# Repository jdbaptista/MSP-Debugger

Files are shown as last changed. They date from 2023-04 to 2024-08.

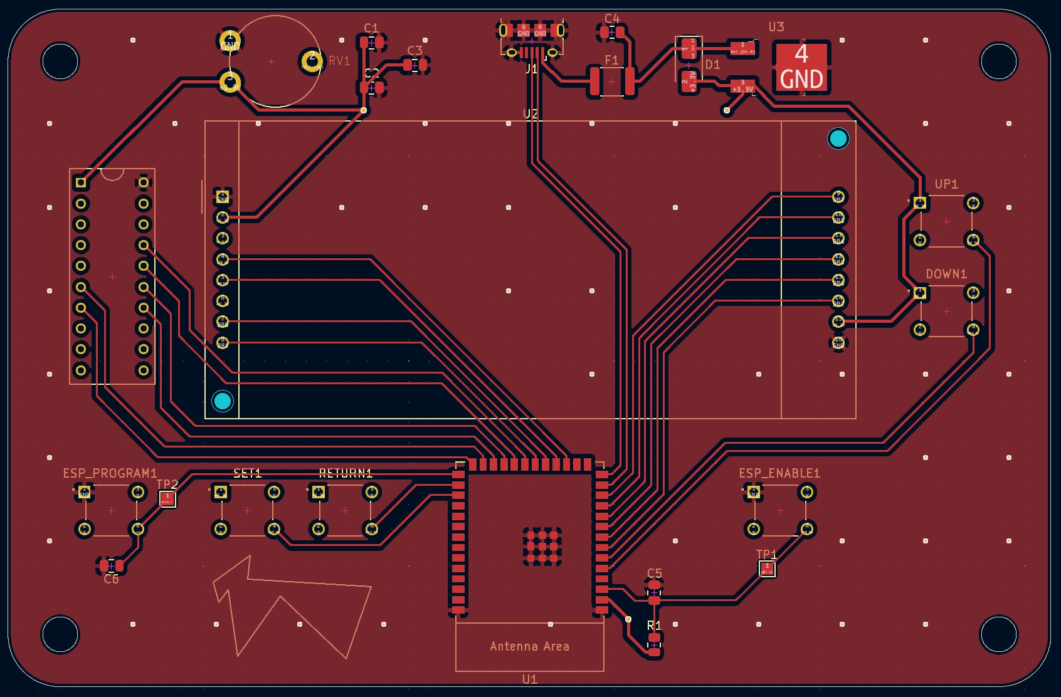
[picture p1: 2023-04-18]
Hardware/frontpcb.jpg

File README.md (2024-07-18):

## Introduction
This project is a combination of bare-metal firmware and hardware that displays the assembly instructions stored in the flash memory of an MSP430G2553, specifically the 20 pin DIP package. Please navigate to each section as necessary: [Example Operation](#example-operation), [Firmware](#firmware).

The device is shown below and supports the following button interactions:
* **UP**: Move back one instruction. Note that moving back one instruction is equivalent to moving lower in memory because the program counter increments positively each target CPU cycle.
  
* **DOWN**: Move forward one instruction. Note that moving forward one instruction is equivalent to moving higher in memory because the program counter increments positively each target CPU cycle.
  
* **FOLLOW JMP**: When the cursor is on a jump instruction, this button moves the cursor to the location specified by the jump. There is also support for following call instructions when the destination operand is an immediate or PC relative offset.
  
* **BIN <-> ASM**: Switch the display view between machine code (binary), displayed in hexadecimal, and RISC assembly instructions. This button highlights that assembly instructions on the target correspond to variable length machine code due to operand types.
  
* **RESET**: Move the cursor back to `0xC000`, which is the start of code memory. This is implemented by simply resetting the MCU.
  
* **USB RESET**: Reset the USB to UART bridge. USB data lines are currently in a broken state, so this button does nothing.

<br>
<p align="center">

</p>

## Example Operation
The following example code from Texas Instruments is used in this example of the device's operation. The code blinks P1.0 repeatedly. Note that all assembly instructions displayed by the device are confirmed to be correct by Code Composer Studio's professional disassembler.
```C
#include <msp430.h>				

void main(void)
{
	WDTCTL = WDTPW | WDTHOLD;		// stop watchdog timer
	P1DIR |= 0x01;					// configure P1.0 as output

	volatile unsigned int i;		// volatile to prevent optimization

	while(1)
	{
		P1OUT ^= 0x01;				// toggle P1.0
		for(i=10000; i>0; i--);     // delay
	}
}
```
The target is loaded with the assembled machine code for this program and placed in the MSP-Debugger. Unfortunately, the display and USB to UART bridge are currently broken, so an MSP-FET (from any MSP430 development board) is connected to the JTAG header of the debugger. The MSP-FET's backchannel UART to USB bridge is used to convey instructions to the user, operating at **9600 baud with an 8-bit frame, no parity bit, and importantly 2 stop bits** (for data integrity). The UART encoding is ISO-8859-1, which is the default in CCS. Immediately after **RESET** the following instruction are extracted from the target and displayed.
```
0xC000: SUB.B #2 SP <
0xC002: MOV.B #0x5A80 &0x0120
0xC008: BIS.B #1 &0x0022
0xC00C: XOR.B #1 &0x0021
```
Using the **DOWN** button moves the cursor from `0xC000` to `0xC002`.
```
0xC002: MOV.B #0x5A80 &0x0120 <
0xC008: BIS.B #1 &0x0022
0xC00C: XOR.B #1 &0x0021
0xC010: MOV.B #0x2710 0x0000(SP)
```
An extremely well trained eye will recognize `&0x0120` as the location of the `WDTCTL` register, which can be confirmed by the peripheral file map on page 18 of the [MSP430G2x53 Datasheet](https://www.ti.com/lit/ds/symlink/msp430g2553.pdf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). Someone without access to the C source code can reference page 363 of the [MSP430G2xx User Guide](https://www.ti.com/lit/ug/slau144k/slau144k.pdf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) to determine that the value `#0x5A80` being moved into `WDTCTL` register writes the correct watchdog password `0x5A00` (`WDTPW`) and suspends the watchdog's operation with `0x0080` (`WDTHOLD`). The watchdog timer will reset the microcontroller if not 'pet' in time by setting `WDTCNTCL`, so this instruction allows the microcontroller to operate without fear of the watchdog.

Using the **BIN <-> ASM** button switches the display from assembly to machine code.
```
0xC002: 0x40B2 0x5A80 0x0120 <
0xC008: 0xD3D2 0x0022 
0xC00C: 0xE3D2 0x0021 
0xC010: 0x40B1 0x2710 0x0000 
```
In this view it can be seen that the instruction to suspend the watchdog takes 3 words, ie. 48 bits, to encode. This is because the `MOV` instruction is a double operand instruction type and the opcode `0x40B2` specifies immediate mode for the first operand, which stores the immediate in the second word, and absolute mode for the second operand, which stores its address in the third word. These modes are internally specified by indirect autoincrement mode with the PC register and indexed mode with the SR register, respectively.

The while loop on line 1 should correspond to a jump instruction somewhere in memory, which we navigate forward to discover.
```
0xC01A: JEQ 0xC00C <
0xC01C: SUB.B #1 0x0000(SP)
0xC020: CMP.B #0 0x0000(SP)
0xC024: JEQ 0xC00C
```
The first jump instruction found is at `0xC01A`, jumping to `0xC00C`. This isn't useful in itself because we don't know what was being compared, which was an instruction that was skipped over.

Using the **UP** button moves the cursor backward by one instruction.
```
0xC016: CMP.B #0 0x0000(SP) <
0xC01A: JEQ 0xC00C
0xC01C: SUB.B #1 0x0000(SP)
0xC020: CMP.B #0 0x0000(SP)
```
This instruction is comparing 0 to some variable located at the stack pointer. This should be `i` from line 12 of the source code because it is the only variable on the stack. Therefore, the jump must correspond to finishing the delay.

Moving the cursor down to the `JEQ 0xC00C` isntruction and using the **FOLLOW JMP** instruction brings the cursor to `0xC00C`.
```
0xC00C: XOR.B #1 &0x0021 <
0xC010: MOV.B #0x2710 0x0000(SP)
0xC016: CMP.B #0 0x0000(SP)
0xC01A: JEQ 0xC00C
```
Finally, it is seen that this `XOR` instruction corresponds to toggling P1.0, as it is the first thing to occur within the while loop!

## Firmware
An MSP430G2553, aside from being the target type, is also used as the main microcontroller for the device. Firmware was developed using register level C programming in Code Composer Studio. Development followed information derived from the [MSP430G2xx User Guide](https://www.ti.com/lit/ug/slau144k/slau144k.pdf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), the [MSP430G2x53 Datasheet](https://www.ti.com/lit/ds/symlink/msp430g2553.pdf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), and the [MSP430 JTAG Programming Guide](https://www.ti.com/lit/ug/slau320aj/slau320aj.pdf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). Three libraries were developed to handle separate facets of the project requirements:

* **UART Driver**: This library handles control of the USCI peripheral to communicate via the UART module. This driver handles configuration of USCI and UART registers, buffering of user printing output, and transmission with a builtin interrupt handler. The driver offers a user-friendly API (ex. `wait_print(char *input)` and `uart_print_hex(uint16_t input)`) optimized for spaced calls. The `wait_print` function is most likely to be used, and currently implements polling until the previous message is finished being sent.
  
* **JTAG Driver**: This library handles interfacing with the target through its JTAG debugging interface. Internally, the interface is implemented as an FSM that is controlled by five input and output lines: TDI, TDO, TMS, TCK, and TEST. This driver works by bit banging the correct FSM sequences on GPIO pins. The API offers a variety of functions (specified by the [JTAG Programming Guide](https://www.ti.com/lit/ug/slau320aj/slau320aj.pdf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)), but the most important for this project is `readMem(uint16_t address)`. This function returns the value stored in the target at a particular memory address.
  
* **Disassembler**: This library handles conversion of machine code to RISC assembly instruction. Information about the representation of each instruction as machine code can be found in the [MSP430G2xx User Guide](https://www.ti.com/lit/ug/slau144k/slau144k.pdf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), specifically the CPU section. The MSP430G2553 contains a 16-bit CPU supporting variable length instructions ranging from a minimum of 1 word to a maximum of 3 words. This presented a significant design challenge as moving one assembly instruction backward is ambiguously a shift of 1, 2, or 3 words in memory with little to hint at which is correct. This ambiguity stems from the various addressing modes (ex. indexed mode) and instruction types (ex. single operand). The disassembler has no remedy to this issue; rather, it is currently solved by the main program which simply begins from the beginning of flash memory and iterates forward until finding the correct instruction. It is planned to speed up this process with a significantly sized cache of nearby instruction locations.

The main program handles user button input with interrupts on the corresponding GPIO pins and a simple button debounce system using the timer peripheral. The program enters LPM3 while waiting for user input, with the timer running on ACLK sourced from the 12kHz VLO waking the program up if a button debounce has finished.

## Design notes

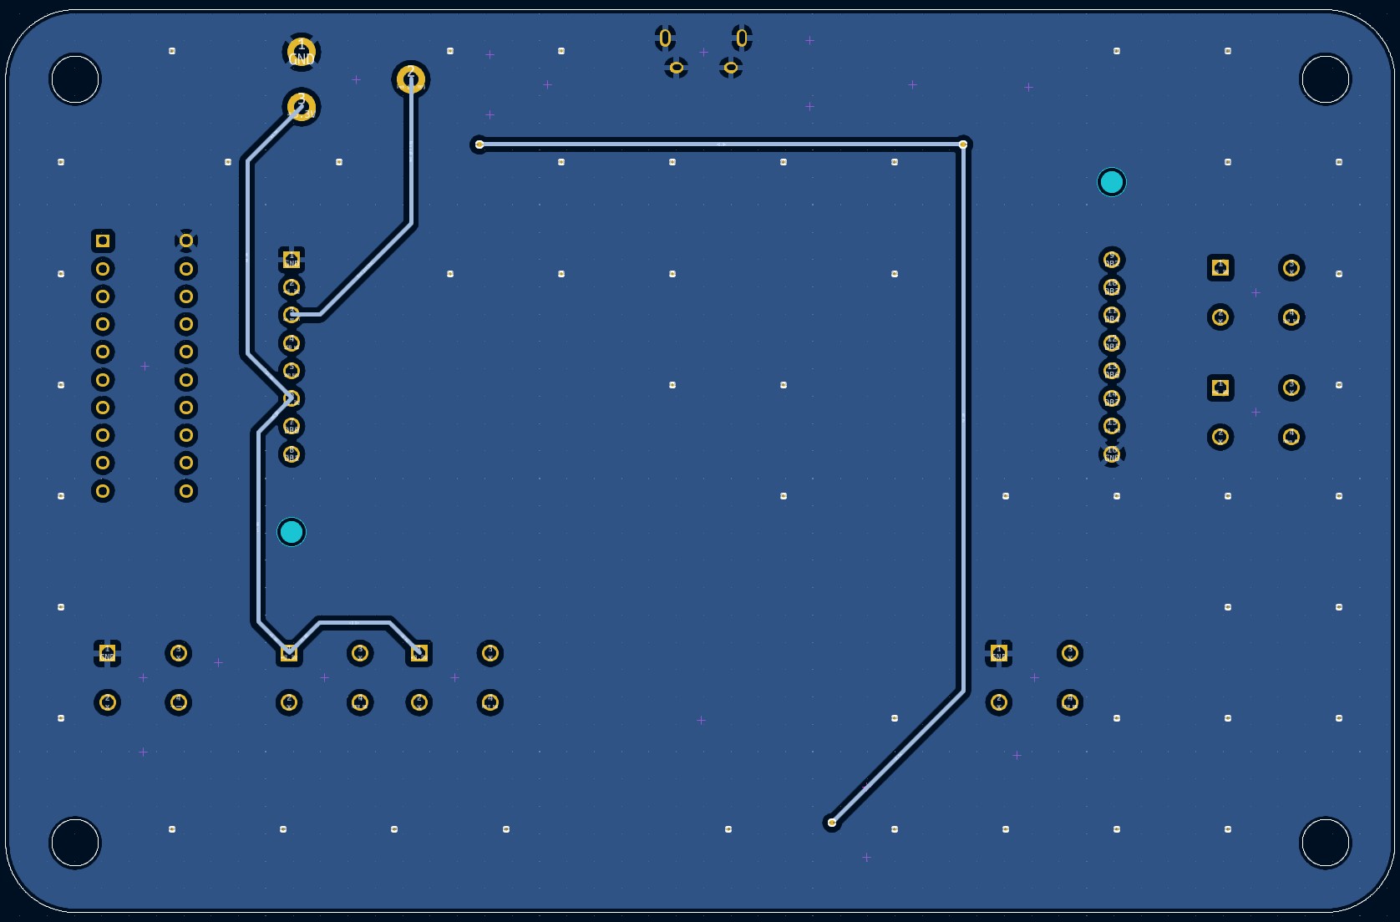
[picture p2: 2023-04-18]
Hardware/backpcb.jpg

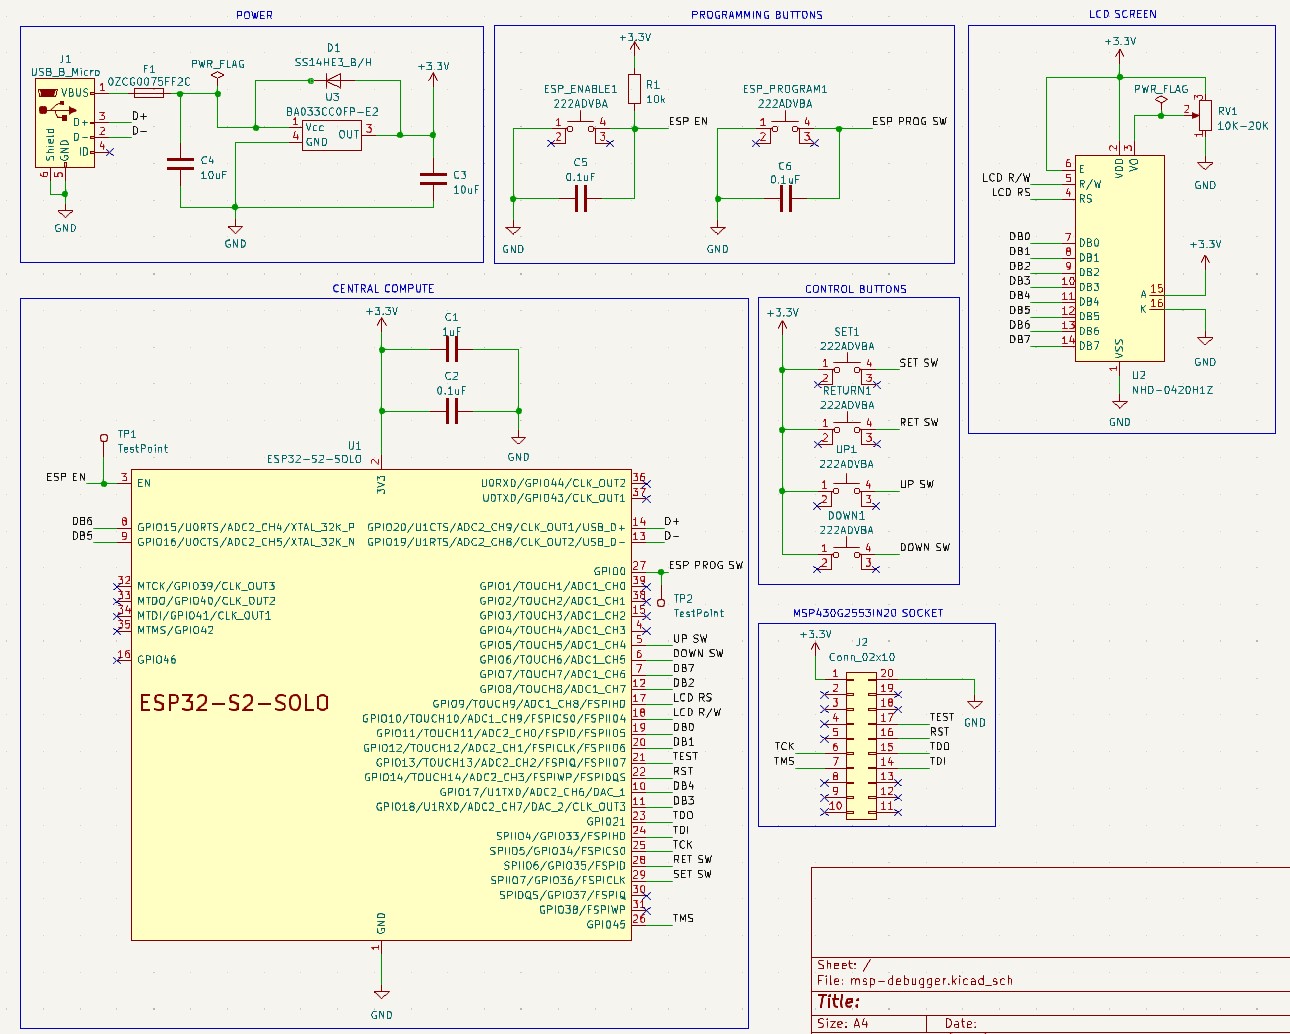
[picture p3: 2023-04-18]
Hardware/schematic.jpg

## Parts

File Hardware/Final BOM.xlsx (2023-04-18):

Custom Reference YOUR NAME (must have) + refdes (optional)! | TOTAL Qty (for 2 boards, or less if budget constrained) | Manufacturer Part # | Digi-key Part#/SKU | Mouser Part#/SKU | Amazon link LAST RESORT | Price/unit ($) | Reference Designator | Description (include component value if applicable)
Jaden Baptista & Anthony Rubio | 1 | NHD-0420H1Z-FSW-GBW-33V3 | NHD-0420H1Z-FSW-GBW-33V3-ND |  |  | $21.38 | U2 | LCD MOD 80DIG 20X4 TRANSFLCT WHT
Jaden Baptista & Anthony Rubio | 1 | PTN10-E20HB20 | 2223-PTN10-E20HB20-ND |  |  | $0.65 | RV1 | TRIMMER POTENTIOMETER, 10MM, HOR
Jaden Baptista & Anthony Rubio | 6 | 222ADVBA | CT3084-ND |  |  | $0.23 | SW(1-6) | SWITCH TACTILE SPST-NO 0.05A 12V
Jaden Baptista & Anthony Rubio | 1 | RC0805JR-0710KL | 311-10KARCT-ND |  |  | $0.10 | R1 | RES 10K OHM 5% 1/8W 0805
Jaden Baptista & Anthony Rubio | 3 | CL21B104KBCNNNC | 1276-1003-1-ND |  |  | $0.10 | C2, C5, C6 | CAP CER 0.1UF 50V X7R 0805
Jaden Baptista & Anthony Rubio | 1 | MSP430G2553IN20 | 296-28429-5-ND |  |  | $3.16 | FLOATING | MSP430 CPU16 MSP430G2xx Microcontroller IC 16-Bit 16MHz 16KB (16K x 8) FLASH 20-PDIP
Jaden Baptista & Anthony Rubio | 1 | 110-83-320-41-001101 | 110-83-320-41-001101-ND |  |  | $2.02 | J2 | CONN IC DIP SOCKET 20POS GOLD
Jaden Baptista & Anthony Rubio | 1 | ESP32-S2-SOLO-2-N4 | 1965-ESP32-S2-SOLO-2-N4-ND |  |  | $2.60 | U1 | WiFi 802.11b/g/n Transceiver Module 2.4GHz PCB Trace Surface Mount
Jaden Baptista & Anthony Rubio | 1 | CL21B105KAFNNNE | 1276-1066-1-ND |  |  | $0.10 | C1 | 1 µF ±10% 25V Ceramic Capacitor X7R 0805 (2012 Metric)
Jaden Baptista & Anthony Rubio | 1 | BA033CC0FP-E2 | BA033CC0FP-E2CT-ND |  |  | $1.41 | U3 | IC REG LINEAR 3.3V 1A TO252-3
Jaden Baptista & Anthony Rubio | 1 | SS14HE3_B/H | 112-SS14HE3_B/HCT-ND |  |  | $0.10 | D1 | Diode 40 V 1A Surface Mount DO-214AC (SMA)
Jaden Baptista & Anthony Rubio | 1 | 10118194-0011LF | 10118194-0011LF-ND |  |  | $0.28 | J1 | USB - micro B USB 2.0 Receptacle Connector 5 Position Surface Mount, Right Angle; Through Hole
Jaden Baptista & Anthony Rubio | 1 | 0ZCG0075FF2C | 507-1763-1-ND |  |  | $0.16 | F1 | PTC RESET FUSE 16V 750MA 1812
Jaden Baptista & Anthony Rubio | 2 | CL21A106KOQNNNE | 1276-1096-1-ND |  |  | $0.10 | C3, C4 | 10 µF ±10% 16V Ceramic Capacitor X5R 0805 (2012 Metric)

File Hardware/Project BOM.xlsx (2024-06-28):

Partner 1 Name: Jaden Baptista | Partner 1 Email: baptistajaden@berkeley.edu | Partner 2 Name: Anthony Rubio | Partner 2 Email: anthonyjrubio@berkeley.edu
 |  |  |  |  |  |  |  |  |  | Total Price for Project
 |  |  |  |  |  |  |  |  |  | $59.54
Qty (for 1 board) | Manufacturer Part # | Digi-key Part#/SKU | Price/unit ($) | Purchase URL | Reference Designator | Description (include component value if applicable) | Datasheet Link | Multiple | Total Qty | Total Price/part ($)
1 | NHD-0440AZ-FL-YBW | NHD-0440AZ-FL-YBW-ND | $28.59 | https://www.digikey.com/en/products/detail/newhaven-display-intl/NHD-0440AZ-FL-YBW/1701247 | U2 | LCD MOD 160 DIG 40X4 TRANS YLW/GRN | https://newhavendisplay.com/content/specs/NHD-0440AZ-FL-YBW.pdf | 1 | 1 | $28.59
10 | RC0805JR-0710KL | 311-10KARCT-ND | $0.10 | https://www.digikey.com/en/products/detail/yageo/RC0805JR-0710KL/728241 | R1 | RES 10K OHM 5% 1/8W 0805 | https://www.yageo.com/upload/media/product/productsearch/datasheet/rchip/PYu-RC_Group_51_RoHS_L_12.pdf | 1 | 10 | $1.00
1 | 3362P-1-103LF | 3362P-103LF-ND | $1.03 | https://www.digikey.com/en/products/detail/bourns-inc/3362P-1-103LF/1088412 | VR1 | TRIMMER 10K OHM 0.5W PC PIN TOP | https://www.bourns.com/docs/Product-Datasheets/3362.pdf | 1 | 1 | $1.03
6 | 222ADVBA | CT3084-ND | $0.23 | https://www.digikey.com/en/products/detail/cts-electrocomponents/222ADVBA/5227977 | SW(1-5) | SWITCH TACTILE SPST-NO 0.05A 12V | https://www.ctscorp.com/wp-content/uploads/222A.pdf | 1 | 6 | $1.38
3 | CL21B104KBCNNNC | 1276-1003-1-ND | $0.10 | https://www.digikey.com/en/products/detail/samsung-electro-mechanics/CL21B104KBCNNNC/3886661 | C2, C5, C6 | CAP CER 0.1UF 50V X7R 0805 | https://media.digikey.com/pdf/Data%20Sheets/Samsung%20PDFs/CL21B104KBCNNN_Spec.pdf | 1 | 3 | $0.30
2 | MSP430G2553IN20 | 296-28429-5-ND | $2.90 | https://www.digikey.com/en/products/detail/texas-instruments/MSP430G2553IN20/2638885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 | U1, J1 | IC MCU 16BIT 16KB FLASH 20DIP | https://www.ti.com/general/docs/suppproductinfo.tsp?distId=10 | 1 | 2 | $5.80
1 | 110-83-320-41-001101 | 110-83-320-41-001101-ND | $2.02 | https://www.digikey.com/en/products/detail/preci-dip/110-83-320-41-001101/4093408 | J2 | CONN IC DIP SOCKET 20POS GOLD | https://www.mouser.com/datasheet/2/571/Preci_Dip_01252017_cat_129-1214522.pdf | 1 | 1 | $2.02
1 | CL21B105KAFNNNE | 1276-1066-1-ND | $0.10 | https://www.digikey.com/en/products/detail/samsung-electro-mechanics/CL21B105KAFNNNE/3886724 | C1 | 1 µF ±10% 25V Ceramic Capacitor X7R 0805 (2012 Metric) | https://media.digikey.com/pdf/Data%20Sheets/Samsung%20PDFs/CL21B105KAFNNNE_Spec.pdf | 1 | 1 | $0.10
1 | BA033CC0FP-E2 | BA033CC0FP-E2CT-ND | $1.41 | https://www.digikey.com/en/products/detail/rohm-semiconductor/BA033CC0FP-E2/722186 | U3 | IC REG LINEAR 3.3V 1A TO252-3 | https://www.rohm.com/datasheet?p=BA033CC0FP&dist=Digi-key&media=referral&campaign=Digi-key | 1 | 1 | $1.41
1 | SS14HE3_B/H | 112-SS14HE3_B/HCT-ND | $0.10 | https://www.digikey.com/en/products/detail/vishay-general-semiconductor-diodes-division/SS14HE3-B-H/6621876 | D1 | Diode 40 V 1A Surface Mount DO-214AC (SMA) | https://www.vishay.com/docs/88746/ss12.pdf | 1 | 1 | $0.10
1 | 10118194-0011LF | 10118194-0011LF-ND | $0.28 | https://www.digikey.com/en/products/detail/amphenol-icc-fci/10118194-0011lf/6817759 | J1 | USB - micro B USB 2.0 Receptacle Connector 5 Position Surface Mount, Right Angle; Through Hole | https://cdn.amphenol-cs.com/media/wysiwyg/files/drawing/10118194.pdf | 1 | 1 | $0.28
1 | 0ZCG0075FF2C | 507-1763-1-ND | $0.16 | https://www.digikey.com/en/products/detail/bel-fuse-inc/0ZCG0075FF2C/4156101 | F1 | PTC RESET FUSE 16V 750MA 1812 | https://www.belfuse.com/resources/datasheets/circuitprotection/ds-cp-0zcg-series.pdf | 1 | 1 | $0.16
2 | CL21A106KOQNNNE | 1276-1096-1-ND | $0.10 | https://www.digikey.com/en/products/detail/samsung-electro-mechanics/CL21A106KOQNNNE/3886754 | C3, C4 | 10 µF ±10% 16V Ceramic Capacitor X5R 0805 (2012 Metric) | https://media.digikey.com/pdf/Data%20Sheets/Samsung%20PDFs/CL21A106KOQNNNE_Spec.pdf | 1 | 2 | $0.20
1 | FT230XS-R | 768-1135-1-ND | $2.26 | https://www.digikey.com/en/products/detail/ftdi-future-technology-devices-international-ltd/FT230XS-R/3029141 | U4 | IC USB SERIAL BASIC UART 16SSOP | https://ftdichip.com/wp-content/uploads/2021/10/DS_FT230X.pdf | 1 | 1 | $2.26
4 | AO4882 | 785-1317-1-ND | $0.52 | https://www.digikey.com/en/products/detail/alpha-omega-semiconductor-inc/AO4882/3060989 |  | Mosfet Array 40V 8A 2W Surface Mount 8-SOIC | https://www.digikey.com/htmldatasheets/production/1034359/0/0/1/ao4882.pdf | 1 | 4 | $2.08
2 | TSW-102-07-G-T | TSW-102-07-G-T-ND | $0.73 | https://www.digikey.com/en/products/detail/samtec-inc/TSW-102-07-G-T/7862063 | J4, J5 | CONN HEADER VERT 6POS 2.54MM | https://mm.digikey.com/Volume0/opasdata/d220001/medias/docus/6129/tsw-xxx-xx-xxx-x-xx-xxx-mkt.pdf | 1 | 2 | $1.46
3 | QPC02SXGN-RC | S9337-ND | $0.10 | https://www.digikey.com/en/products/detail/sullins-connector-solutions/QPC02SXGN-RC/2618262 |  | CONN JUMPER SHORTING .100" GOLD | https://s3.amazonaws.com/catalogspreads-pdf/PAGE128-129%20.100%20JUMPER.pdf | 1 | 3 | 0.3
2 | TD-109-T-A | SAM1114-09-ND | $3.60 | https://www.digikey.com/en/products/detail/samtec-inc/TD-109-T-A/1105549 |  | CONN HEADER VERT 18POS 2.54MM | https://suddendocs.samtec.com/catalog_english/td.pdf | 1 | 2 | 7.2
2 | TS-110-T-A | SAM1112-10-ND | $1.94 | https://www.digikey.com/en/products/detail/samtec-inc/TS-110-T-A/1105484 |  | CONN HEADER VERT 10POS 2.54MM | https://suddendocs.samtec.com/catalog_english/td.pdf | 1 | 2 | 3.88
 |  |  |  |  |  |  |  |  | 0 | 0
 |  |  |  |  |  |  |  |  | 0 | 0
 |  |  |  |  |  |  |  |  | 0 | 0
 |  |  |  |  |  |  |  |  | 0 | 0
 |  |  |  |  |  |  |  |  | 0 | 0
 |  |  |  |  |  |  |  |  | 0 | 0
 |  |  |  |  |  |  |  |  | 0 | 0
 |  |  |  |  |  |  |  |  | 0 | 0
 |  |  |  |  |  |  |  |  | 0 | 0
 |  |  |  |  |  |  |  |  | 0 | 0
 |  |  |  |  |  |  |  |  | 0 | 0
 |  |  |  |  |  |  |  |  | 0 | 0
 |  |  |  |  |  |  |  |  | 0 | 0
 |  |  |  |  |  |  |  |  | 0 | 0
 |  |  |  |  |  |  |  |  | 0 | 0
 |  |  |  |  |  |  |  |  | 0 | 0
 |  |  |  |  |  |  |  |  | 0 | 0
 |  |  |  |  |  |  |  |  | 0 | 0
 |  |  |  |  |  |  |  |  | 0 | 0
 |  |  |  |  |  |  |  |  | 0 | 0
 |  |  |  |  |  |  |  |  | 0 | 0
 |  |  |  |  |  |  |  |  | 0 | 0
 |  |  |  |  |  |  |  |  | 0 | 0
 |  |  |  |  |  |  |  |  | 0 | 0
 |  |  |  |  |  |  |  |  | 0 | 0
 |  |  |  |  |  |  |  |  | 0 | 0
 |  |  |  |  |  |  |  |  | 0 | 0
 |  |  |  |  |  |  |  |  | 0 | 0
 |  |  |  |  |  |  |  |  | 0 | 0
 |  |  |  |  |  |  |  |  | 0 | 0
 |  |  |  |  |  |  |  |  | 0 | 0
 |  |  |  |  |  |  |  |  | 0 | 0
 |  |  |  |  |  |  |  |  | 0 | 0
 |  |  |  |  |  |  |  |  | 0 | 0
 |  |  |  |  |  |  |  |  | 0 | 0
 |  |  |  |  |  |  |  |  | 0 | 0
 |  |  |  |  |  |  |  |  | 0 | 0
 |  |  |  |  |  |  |  |  | 0 | 0
 |  |  |  |  |  |  |  |  | 0 | 0
 |  |  |  |  |  |  |  |  | 0 | 0
 |  |  |  |  |  |  |  |  | 0 | 0
 |  |  |  |  |  |  |  |  | 0 | 0
 |  |  |  |  |  |  |  |  | 0 | 0
 |  |  |  |  |  |  |  |  | 0 | 0
 |  |  |  |  |  |  |  |  | 0 | 0
 |  |  |  |  |  |  |  |  | 0 | 0
 |  |  |  |  |  |  |  |  | 0 | 0
 |  |  |  |  |  |  |  |  | 0 | 0
 |  |  |  |  |  |  |  |  | 0 | 0
 |  |  |  |  |  |  |  |  | 0 | 0
 |  |  |  |  |  |  |  |  | 0 | 0
 |  |  |  |  |  |  |  |  | 0 | 0
 |  |  |  |  |  |  |  |  | 0 | 0
 |  |  |  |  |  |  |  |  | 0 | 0
 |  |  |  |  |  |  |  |  | 0 | 0
 |  |  |  |  |  |  |  |  | 0 | 0
 |  |  |  |  |  |  |  |  | 0 | 0
 |  |  |  |  |  |  |  |  | 0 | 0
 |  |  |  |  |  |  |  |  | 0 | 0
 |  |  |  |  |  |  |  |  | 0 | 0
 |  |  |  |  |  |  |  |  | 0 | 0
 |  |  |  |  |  |  |  |  | 0 | 0
 |  |  |  |  |  |  |  |  | 0 | 0
 |  |  |  |  |  |  |  |  | 0 | 0
 |  |  |  |  |  |  |  |  | 0 | 0
 |  |  |  |  |  |  |  |  | 0 | 0
 |  |  |  |  |  |  |  |  | 0 | 0
 |  |  |  |  |  |  |  |  | 0 | 0
 |  |  |  |  |  |  |  |  | 0 | 0
 |  |  |  |  |  |  |  |  | 0 | 0
 |  |  |  |  |  |  |  |  | 0 | 0
 |  |  |  |  |  |  |  |  | 0 | 0
 |  |  |  |  |  |  |  |  | 0 | 0
 |  |  |  |  |  |  |  |  | 0 | 0
 |  |  |  |  |  |  |  |  | 0 | 0
 |  |  |  |  |  |  |  |  | 0 | 0
 |  |  |  |  |  |  |  |  | 0 | 0
 |  |  |  |  |  |  |  |  | 0 | 0
 |  |  |  |  |  |  |  |  | 0 | 0
 |  |  |  |  |  |  |  |  | 0 | 0
 |  |  |  |  |  |  |  |  | 0 | 0
 |  |  |  |  |  |  |  |  | 0 | 0
 |  |  |  |  |  |  |  |  | 0 | 0
 |  |  |  |  |  |  |  |  | 0 | 0
 |  |  |  |  |  |  |  |  | 0 | 0
 |  |  |  |  |  |  |  |  | 0 | 0
 |  |  |  |  |  |  |  |  | 0 | 0
 |  |  |  |  |  |  |  |  | 0 | 0
 |  |  |  |  |  |  |  |  | 0 | 0
 |  |  |  |  |  |  |  |  | 0 | 0
 |  |  |  |  |  |  |  |  | 0 | 0
 |  |  |  |  |  |  |  |  | 0 | 0
 |  |  |  |  |  |  |  |  | 0 | 0
 |  |  |  |  |  |  |  |  | 0 | 0
 |  |  |  |  |  |  |  |  | 0 | 0
 |  |  |  |  |  |  |  |  | 0 | 0
 |  |  |  |  |  |  |  |  | 0 | 0
 |  |  |  |  |  |  |  |  | 0 | 0
 |  |  |  |  |  |  |  |  | 0 | 0
 |  |  |  |  |  |  |  |  | 0 | 0
 |  |  |  |  |  |  |  |  | 0 | 0
 |  |  |  |  |  |  |  |  | 0 | 0
 |  |  |  |  |  |  |  |  | 0 | 0
 |  |  |  |  |  |  |  |  | 0 | 0
 |  |  |  |  |  |  |  |  | 0 | 0
 |  |  |  |  |  |  |  |  | 0 | 0
 |  |  |  |  |  |  |  |  | 0 | 0
 |  |  |  |  |  |  |  |  | 0 | 0
 |  |  |  |  |  |  |  |  | 0 | 0
 |  |  |  |  |  |  |  |  | 0 | 0
 |  |  |  |  |  |  |  |  | 0 | 0
 |  |  |  |  |  |  |  |  | 0 | 0
 |  |  |  |  |  |  |  |  | 0 | 0
 |  |  |  |  |  |  |  |  | 0 | 0
 |  |  |  |  |  |  |  |  | 0 | 0
 |  |  |  |  |  |  |  |  | 0 | 0
 |  |  |  |  |  |  |  |  | 0 | 0
 |  |  |  |  |  |  |  |  | 0 | 0
 |  |  |  |  |  |  |  |  | 0 | 0
 |  |  |  |  |  |  |  |  | 0 | 0
 |  |  |  |  |  |  |  |  | 0 | 0
 |  |  |  |  |  |  |  |  | 0 | 0
 |  |  |  |  |  |  |  |  | 0 | 0
 |  |  |  |  |  |  |  |  | 0 | 0
 |  |  |  |  |  |  |  |  | 0 | 0
 |  |  |  |  |  |  |  |  | 0 | 0
 |  |  |  |  |  |  |  |  | 0 | 0
 |  |  |  |  |  |  |  |  | 0 | 0
 |  |  |  |  |  |  |  |  | 0 | 0
 |  |  |  |  |  |  |  |  | 0 | 0
 |  |  |  |  |  |  |  |  | 0 | 0
 |  |  |  |  |  |  |  |  | 0 | 0
 |  |  |  |  |  |  |  |  | 0 | 0
 |  |  |  |  |  |  |  |  | 0 | 0
 |  |  |  |  |  |  |  |  | 0 | 0
 |  |  |  |  |  |  |  |  | 0 | 0
 |  |  |  |  |  |  |  |  | 0 | 0
 |  |  |  |  |  |  |  |  | 0 | 0
 |  |  |  |  |  |  |  |  | 0 | 0
 |  |  |  |  |  |  |  |  | 0 | 0
 |  |  |  |  |  |  |  |  | 0 | 0
 |  |  |  |  |  |  |  |  | 0 | 0
 |  |  |  |  |  |  |  |  | 0 | 0
 |  |  |  |  |  |  |  |  | 0 | 0
 |  |  |  |  |  |  |  |  | 0 | 0
 |  |  |  |  |  |  |  |  | 0 | 0
 |  |  |  |  |  |  |  |  | 0 | 0
 |  |  |  |  |  |  |  |  | 0 | 0
 |  |  |  |  |  |  |  |  | 0 | 0
 |  |  |  |  |  |  |  |  | 0 | 0
 |  |  |  |  |  |  |  |  | 0 | 0
 |  |  |  |  |  |  |  |  | 0 | 0
 |  |  |  |  |  |  |  |  | 0 | 0
 |  |  |  |  |  |  |  |  | 0 | 0
 |  |  |  |  |  |  |  |  | 0 | 0
 |  |  |  |  |  |  |  |  | 0 | 0
 |  |  |  |  |  |  |  |  | 0 | 0
 |  |  |  |  |  |  |  |  | 0 | 0
 |  |  |  |  |  |  |  |  | 0 | 0
 |  |  |  |  |  |  |  |  | 0 | 0
 |  |  |  |  |  |  |  |  | 0 | 0
 |  |  |  |  |  |  |  |  | 0 | 0
 |  |  |  |  |  |  |  |  | 0 | 0
 |  |  |  |  |  |  |  |  | 0 | 0
 |  |  |  |  |  |  |  |  | 0 | 0
 |  |  |  |  |  |  |  |  | 0 | 0
 |  |  |  |  |  |  |  |  | 0 | 0
 |  |  |  |  |  |  |  |  | 0 | 0
 |  |  |  |  |  |  |  |  | 0 | 0
 |  |  |  |  |  |  |  |  | 0 | 0
 |  |  |  |  |  |  |  |  | 0 | 0
 |  |  |  |  |  |  |  |  | 0 | 0
 |  |  |  |  |  |  |  |  | 0 | 0
 |  |  |  |  |  |  |  |  | 0 | 0
 |  |  |  |  |  |  |  |  | 0 | 0
 |  |  |  |  |  |  |  |  | 0 | 0
 |  |  |  |  |  |  |  |  | 0 | 0
 |  |  |  |  |  |  |  |  | 0 | 0
 |  |  |  |  |  |  |  |  | 0 | 0
 |  |  |  |  |  |  |  |  | 0 | 0
 |  |  |  |  |  |  |  |  | 0 | 0
 |  |  |  |  |  |  |  |  | 0 | 0
 |  |  |  |  |  |  |  |  | 0 | 0
 |  |  |  |  |  |  |  |  | 0 | 0
 |  |  |  |  |  |  |  |  | 0 | 0
 |  |  |  |  |  |  |  |  | 0 | 0
 |  |  |  |  |  |  |  |  | 0 | 0
 |  |  |  |  |  |  |  |  | 0 | 0
 |  |  |  |  |  |  |  |  | 0 | 0
 |  |  |  |  |  |  |  |  | 0 | 0
 |  |  |  |  |  |  |  |  | 0 | 0
 |  |  |  |  |  |  |  |  | 0 | 0
 |  |  |  |  |  |  |  |  | 0 | 0
 |  |  |  |  |  |  |  |  | 0 | 0
 |  |  |  |  |  |  |  |  | 0 | 0
 |  |  |  |  |  |  |  |  | 0 | 0
 |  |  |  |  |  |  |  |  | 0 | 0
 |  |  |  |  |  |  |  |  | 0 | 0
 |  |  |  |  |  |  |  |  | 0 | 0
 |  |  |  |  |  |  |  |  | 0 | 0
 |  |  |  |  |  |  |  |  | 0 | 0
 |  |  |  |  |  |  |  |  | 0 | 0
 |  |  |  |  |  |  |  |  | 0 | 0
 |  |  |  |  |  |  |  |  | 0 | 0
 |  |  |  |  |  |  |  |  | 0 | 0
 |  |  |  |  |  |  |  |  | 0 | 0
 |  |  |  |  |  |  |  |  | 0 | 0
 |  |  |  |  |  |  |  |  | 0 | 0
 |  |  |  |  |  |  |  |  | 0 | 0
 |  |  |  |  |  |  |  |  | 0 | 0
 |  |  |  |  |  |  |  |  | 0 | 0
 |  |  |  |  |  |  |  |  | 0 | 0
 |  |  |  |  |  |  |  |  | 0 | 0
 |  |  |  |  |  |  |  |  | 0 | 0
 |  |  |  |  |  |  |  |  | 0 | 0
 |  |  |  |  |  |  |  |  | 0 | 0
 |  |  |  |  |  |  |  |  | 0 | 0
 |  |  |  |  |  |  |  |  | 0 | 0
 |  |  |  |  |  |  |  |  | 0 | 0
 |  |  |  |  |  |  |  |  | 0 | 0
 |  |  |  |  |  |  |  |  | 0 | 0
 |  |  |  |  |  |  |  |  | 0 | 0
 |  |  |  |  |  |  |  |  | 0 | 0
 |  |  |  |  |  |  |  |  | 0 | 0
 |  |  |  |  |  |  |  |  | 0 | 0
 |  |  |  |  |  |  |  |  | 0 | 0
 |  |  |  |  |  |  |  |  | 0 | 0
 |  |  |  |  |  |  |  |  | 0 | 0
 |  |  |  |  |  |  |  |  | 0 | 0
 |  |  |  |  |  |  |  |  | 0 | 0
 |  |  |  |  |  |  |  |  | 0 | 0
 |  |  |  |  |  |  |  |  | 0 | 0
 |  |  |  |  |  |  |  |  | 0 | 0
 |  |  |  |  |  |  |  |  | 0 | 0
 |  |  |  |  |  |  |  |  | 0 | 0
 |  |  |  |  |  |  |  |  | 0 | 0
 |  |  |  |  |  |  |  |  | 0 | 0
 |  |  |  |  |  |  |  |  | 0 | 0
 |  |  |  |  |  |  |  |  | 0 | 0
 |  |  |  |  |  |  |  |  | 0 | 0
 |  |  |  |  |  |  |  |  | 0 | 0
 |  |  |  |  |  |  |  |  | 0 | 0
 |  |  |  |  |  |  |  |  | 0 | 0
 |  |  |  |  |  |  |  |  | 0 | 0
 |  |  |  |  |  |  |  |  | 0 | 0
 |  |  |  |  |  |  |  |  | 0 | 0
 |  |  |  |  |  |  |  |  | 0 | 0
 |  |  |  |  |  |  |  |  | 0 | 0
 |  |  |  |  |  |  |  |  | 0 | 0
 |  |  |  |  |  |  |  |  | 0 | 0
 |  |  |  |  |  |  |  |  | 0 | 0
 |  |  |  |  |  |  |  |  | 0 | 0
 |  |  |  |  |  |  |  |  | 0 | 0
 |  |  |  |  |  |  |  |  | 0 | 0
 |  |  |  |  |  |  |  |  | 0 | 0
 |  |  |  |  |  |  |  |  | 0 | 0
 |  |  |  |  |  |  |  |  | 0 | 0
 |  |  |  |  |  |  |  |  | 0 | 0
 |  |  |  |  |  |  |  |  | 0 | 0
 |  |  |  |  |  |  |  |  | 0 | 0
 |  |  |  |  |  |  |  |  | 0 | 0
 |  |  |  |  |  |  |  |  | 0 | 0
 |  |  |  |  |  |  |  |  | 0 | 0
 |  |  |  |  |  |  |  |  | 0 | 0
 |  |  |  |  |  |  |  |  | 0 | 0
 |  |  |  |  |  |  |  |  | 0 | 0
 |  |  |  |  |  |  |  |  | 0 | 0
 |  |  |  |  |  |  |  |  | 0 | 0
 |  |  |  |  |  |  |  |  | 0 | 0
 |  |  |  |  |  |  |  |  | 0 | 0
 |  |  |  |  |  |  |  |  | 0 | 0
 |  |  |  |  |  |  |  |  | 0 | 0
 |  |  |  |  |  |  |  |  | 0 | 0
 |  |  |  |  |  |  |  |  | 0 | 0
 |  |  |  |  |  |  |  |  | 0 | 0
 |  |  |  |  |  |  |  |  | 0 | 0
 |  |  |  |  |  |  |  |  | 0 | 0
 |  |  |  |  |  |  |  |  | 0 | 0
 |  |  |  |  |  |  |  |  | 0 | 0
 |  |  |  |  |  |  |  |  | 0 | 0
 |  |  |  |  |  |  |  |  | 0 | 0
 |  |  |  |  |  |  |  |  | 0 | 0
 |  |  |  |  |  |  |  |  | 0 | 0
 |  |  |  |  |  |  |  |  | 0 | 0
 |  |  |  |  |  |  |  |  | 0 | 0
 |  |  |  |  |  |  |  |  | 0 | 0
 |  |  |  |  |  |  |  |  | 0 | 0
 |  |  |  |  |  |  |  |  | 0 | 0
 |  |  |  |  |  |  |  |  | 0 | 0
 |  |  |  |  |  |  |  |  | 0 | 0
 |  |  |  |  |  |  |  |  | 0 | 0
 |  |  |  |  |  |  |  |  | 0 | 0
 |  |  |  |  |  |  |  |  | 0 | 0
 |  |  |  |  |  |  |  |  | 0 | 0
 |  |  |  |  |  |  |  |  | 0 | 0
 |  |  |  |  |  |  |  |  | 0 | 0
 |  |  |  |  |  |  |  |  | 0 | 0
 |  |  |  |  |  |  |  |  | 0 | 0
 |  |  |  |  |  |  |  |  | 0 | 0
 |  |  |  |  |  |  |  |  | 0 | 0
 |  |  |  |  |  |  |  |  | 0 | 0
 |  |  |  |  |  |  |  |  | 0 | 0
 |  |  |  |  |  |  |  |  | 0 | 0
 |  |  |  |  |  |  |  |  | 0 | 0
 |  |  |  |  |  |  |  |  | 0 | 0
 |  |  |  |  |  |  |  |  | 0 | 0
 |  |  |  |  |  |  |  |  | 0 | 0
 |  |  |  |  |  |  |  |  | 0 | 0
 |  |  |  |  |  |  |  |  | 0 | 0
 |  |  |  |  |  |  |  |  | 0 | 0
 |  |  |  |  |  |  |  |  | 0 | 0
 |  |  |  |  |  |  |  |  | 0 | 0
 |  |  |  |  |  |  |  |  | 0 | 0
 |  |  |  |  |  |  |  |  | 0 | 0
 |  |  |  |  |  |  |  |  | 0 | 0
 |  |  |  |  |  |  |  |  | 0 | 0
 |  |  |  |  |  |  |  |  | 0 | 0
 |  |  |  |  |  |  |  |  | 0 | 0
 |  |  |  |  |  |  |  |  | 0 | 0
 |  |  |  |  |  |  |  |  | 0 | 0
 |  |  |  |  |  |  |  |  | 0 | 0
 |  |  |  |  |  |  |  |  | 0 | 0
 |  |  |  |  |  |  |  |  | 0 | 0
 |  |  |  |  |  |  |  |  | 0 | 0
 |  |  |  |  |  |  |  |  | 0 | 0
 |  |  |  |  |  |  |  |  | 0 | 0
 |  |  |  |  |  |  |  |  | 0 | 0
 |  |  |  |  |  |  |  |  | 0 | 0
 |  |  |  |  |  |  |  |  | 0 | 0
 |  |  |  |  |  |  |  |  | 0 | 0
 |  |  |  |  |  |  |  |  | 0 | 0
 |  |  |  |  |  |  |  |  | 0 | 0
 |  |  |  |  |  |  |  |  | 0 | 0
 |  |  |  |  |  |  |  |  | 0 | 0
 |  |  |  |  |  |  |  |  | 0 | 0
 |  |  |  |  |  |  |  |  | 0 | 0
 |  |  |  |  |  |  |  |  | 0 | 0
 |  |  |  |  |  |  |  |  | 0 | 0
 |  |  |  |  |  |  |  |  | 0 | 0
 |  |  |  |  |  |  |  |  | 0 | 0
 |  |  |  |  |  |  |  |  | 0 | 0
 |  |  |  |  |  |  |  |  | 0 | 0
 |  |  |  |  |  |  |  |  | 0 | 0
 |  |  |  |  |  |  |  |  | 0 | 0
 |  |  |  |  |  |  |  |  | 0 | 0
 |  |  |  |  |  |  |  |  | 0 | 0
 |  |  |  |  |  |  |  |  | 0 | 0
 |  |  |  |  |  |  |  |  | 0 | 0
 |  |  |  |  |  |  |  |  | 0 | 0
 |  |  |  |  |  |  |  |  | 0 | 0
 |  |  |  |  |  |  |  |  | 0 | 0
 |  |  |  |  |  |  |  |  | 0 | 0
 |  |  |  |  |  |  |  |  | 0 | 0
 |  |  |  |  |  |  |  |  | 0 | 0
 |  |  |  |  |  |  |  |  | 0 | 0
 |  |  |  |  |  |  |  |  | 0 | 0
 |  |  |  |  |  |  |  |  | 0 | 0
 |  |  |  |  |  |  |  |  | 0 | 0
 |  |  |  |  |  |  |  |  | 0 | 0
 |  |  |  |  |  |  |  |  | 0 | 0
 |  |  |  |  |  |  |  |  | 0 | 0
 |  |  |  |  |  |  |  |  | 0 | 0
 |  |  |  |  |  |  |  |  | 0 | 0
 |  |  |  |  |  |  |  |  | 0 | 0
 |  |  |  |  |  |  |  |  | 0 | 0
 |  |  |  |  |  |  |  |  | 0 | 0
 |  |  |  |  |  |  |  |  | 0 | 0
 |  |  |  |  |  |  |  |  | 0 | 0
 |  |  |  |  |  |  |  |  | 0 | 0
 |  |  |  |  |  |  |  |  | 0 | 0
 |  |  |  |  |  |  |  |  | 0 | 0
 |  |  |  |  |  |  |  |  | 0 | 0
 |  |  |  |  |  |  |  |  | 0 | 0
 |  |  |  |  |  |  |  |  | 0 | 0
 |  |  |  |  |  |  |  |  | 0 | 0
 |  |  |  |  |  |  |  |  | 0 | 0
 |  |  |  |  |  |  |  |  | 0 | 0
 |  |  |  |  |  |  |  |  | 0 | 0
 |  |  |  |  |  |  |  |  | 0 | 0
 |  |  |  |  |  |  |  |  | 0 | 0
 |  |  |  |  |  |  |  |  | 0 | 0
 |  |  |  |  |  |  |  |  | 0 | 0
 |  |  |  |  |  |  |  |  | 0 | 0
 |  |  |  |  |  |  |  |  | 0 | 0
 |  |  |  |  |  |  |  |  | 0 | 0
 |  |  |  |  |  |  |  |  | 0 | 0
 |  |  |  |  |  |  |  |  | 0 | 0
 |  |  |  |  |  |  |  |  | 0 | 0
 |  |  |  |  |  |  |  |  | 0 | 0
 |  |  |  |  |  |  |  |  | 0 | 0
 |  |  |  |  |  |  |  |  | 0 | 0
 |  |  |  |  |  |  |  |  | 0 | 0
 |  |  |  |  |  |  |  |  | 0 | 0
 |  |  |  |  |  |  |  |  | 0 | 0
 |  |  |  |  |  |  |  |  | 0 | 0
 |  |  |  |  |  |  |  |  | 0 | 0
 |  |  |  |  |  |  |  |  | 0 | 0
 |  |  |  |  |  |  |  |  | 0 | 0
 |  |  |  |  |  |  |  |  | 0 | 0
 |  |  |  |  |  |  |  |  | 0 | 0
 |  |  |  |  |  |  |  |  | 0 | 0
 |  |  |  |  |  |  |  |  | 0 | 0
 |  |  |  |  |  |  |  |  | 0 | 0
 |  |  |  |  |  |  |  |  | 0 | 0
 |  |  |  |  |  |  |  |  | 0 | 0
 |  |  |  |  |  |  |  |  | 0 | 0
 |  |  |  |  |  |  |  |  | 0 | 0
 |  |  |  |  |  |  |  |  | 0 | 0
 |  |  |  |  |  |  |  |  | 0 | 0
 |  |  |  |  |  |  |  |  | 0 | 0
 |  |  |  |  |  |  |  |  | 0 | 0
 |  |  |  |  |  |  |  |  | 0 | 0
 |  |  |  |  |  |  |  |  | 0 | 0
 |  |  |  |  |  |  |  |  | 0 | 0
 |  |  |  |  |  |  |  |  | 0 | 0
 |  |  |  |  |  |  |  |  | 0 | 0
 |  |  |  |  |  |  |  |  | 0 | 0
 |  |  |  |  |  |  |  |  | 0 | 0
 |  |  |  |  |  |  |  |  | 0 | 0
 |  |  |  |  |  |  |  |  | 0 | 0
 |  |  |  |  |  |  |  |  | 0 | 0
 |  |  |  |  |  |  |  |  | 0 | 0
 |  |  |  |  |  |  |  |  | 0 | 0
 |  |  |  |  |  |  |  |  | 0 | 0
 |  |  |  |  |  |  |  |  | 0 | 0
 |  |  |  |  |  |  |  |  | 0 | 0
 |  |  |  |  |  |  |  |  | 0 | 0
 |  |  |  |  |  |  |  |  | 0 | 0
 |  |  |  |  |  |  |  |  | 0 | 0
 |  |  |  |  |  |  |  |  | 0 | 0
 |  |  |  |  |  |  |  |  | 0 | 0
 |  |  |  |  |  |  |  |  | 0 | 0
 |  |  |  |  |  |  |  |  | 0 | 0
 |  |  |  |  |  |  |  |  | 0 | 0
 |  |  |  |  |  |  |  |  | 0 | 0
 |  |  |  |  |  |  |  |  | 0 | 0
 |  |  |  |  |  |  |  |  | 0 | 0
 |  |  |  |  |  |  |  |  | 0 | 0
 |  |  |  |  |  |  |  |  | 0 | 0
 |  |  |  |  |  |  |  |  | 0 | 0
 |  |  |  |  |  |  |  |  | 0 | 0
 |  |  |  |  |  |  |  |  | 0 | 0
 |  |  |  |  |  |  |  |  | 0 | 0
 |  |  |  |  |  |  |  |  | 0 | 0
 |  |  |  |  |  |  |  |  | 0 | 0
 |  |  |  |  |  |  |  |  | 0 | 0
 |  |  |  |  |  |  |  |  | 0 | 0
 |  |  |  |  |  |  |  |  | 0 | 0
 |  |  |  |  |  |  |  |  | 0 | 0
 |  |  |  |  |  |  |  |  | 0 | 0
 |  |  |  |  |  |  |  |  | 0 | 0
 |  |  |  |  |  |  |  |  | 0 | 0
 |  |  |  |  |  |  |  |  | 0 | 0
 |  |  |  |  |  |  |  |  | 0 | 0
 |  |  |  |  |  |  |  |  | 0 | 0
 |  |  |  |  |  |  |  |  | 0 | 0
 |  |  |  |  |  |  |  |  | 0 | 0
 |  |  |  |  |  |  |  |  | 0 | 0
 |  |  |  |  |  |  |  |  | 0 | 0
 |  |  |  |  |  |  |  |  | 0 | 0
 |  |  |  |  |  |  |  |  | 0 | 0
 |  |  |  |  |  |  |  |  | 0 | 0
 |  |  |  |  |  |  |  |  | 0 | 0
 |  |  |  |  |  |  |  |  | 0 | 0
 |  |  |  |  |  |  |  |  | 0 | 0
 |  |  |  |  |  |  |  |  | 0 | 0
 |  |  |  |  |  |  |  |  | 0 | 0
 |  |  |  |  |  |  |  |  | 0 | 0
 |  |  |  |  |  |  |  |  | 0 | 0
 |  |  |  |  |  |  |  |  | 0 | 0
 |  |  |  |  |  |  |  |  | 0 | 0
 |  |  |  |  |  |  |  |  | 0 | 0
 |  |  |  |  |  |  |  |  | 0 | 0
 |  |  |  |  |  |  |  |  | 0 | 0
 |  |  |  |  |  |  |  |  | 0 | 0
 |  |  |  |  |  |  |  |  | 0 | 0
 |  |  |  |  |  |  |  |  | 0 | 0
 |  |  |  |  |  |  |  |  | 0 | 0
 |  |  |  |  |  |  |  |  | 0 | 0
 |  |  |  |  |  |  |  |  | 0 | 0
 |  |  |  |  |  |  |  |  | 0 | 0
 |  |  |  |  |  |  |  |  | 0 | 0
 |  |  |  |  |  |  |  |  | 0 | 0
 |  |  |  |  |  |  |  |  | 0 | 0
 |  |  |  |  |  |  |  |  | 0 | 0
 |  |  |  |  |  |  |  |  | 0 | 0
 |  |  |  |  |  |  |  |  | 0 | 0
 |  |  |  |  |  |  |  |  | 0 | 0
 |  |  |  |  |  |  |  |  | 0 | 0
 |  |  |  |  |  |  |  |  | 0 | 0
 |  |  |  |  |  |  |  |  | 0 | 0
 |  |  |  |  |  |  |  |  | 0 | 0
 |  |  |  |  |  |  |  |  | 0 | 0
 |  |  |  |  |  |  |  |  | 0 | 0
 |  |  |  |  |  |  |  |  | 0 | 0
 |  |  |  |  |  |  |  |  | 0 | 0
 |  |  |  |  |  |  |  |  | 0 | 0
 |  |  |  |  |  |  |  |  | 0 | 0
 |  |  |  |  |  |  |  |  | 0 | 0
 |  |  |  |  |  |  |  |  | 0 | 0
 |  |  |  |  |  |  |  |  | 0 | 0
 |  |  |  |  |  |  |  |  | 0 | 0
 |  |  |  |  |  |  |  |  | 0 | 0
 |  |  |  |  |  |  |  |  | 0 | 0
 |  |  |  |  |  |  |  |  | 0 | 0
 |  |  |  |  |  |  |  |  | 0 | 0
 |  |  |  |  |  |  |  |  | 0 | 0
 |  |  |  |  |  |  |  |  | 0 | 0
 |  |  |  |  |  |  |  |  | 0 | 0
 |  |  |  |  |  |  |  |  | 0 | 0
 |  |  |  |  |  |  |  |  | 0 | 0
 |  |  |  |  |  |  |  |  | 0 | 0
 |  |  |  |  |  |  |  |  | 0 | 0
 |  |  |  |  |  |  |  |  | 0 | 0
 |  |  |  |  |  |  |  |  | 0 | 0
 |  |  |  |  |  |  |  |  | 0 | 0
 |  |  |  |  |  |  |  |  | 0 | 0
 |  |  |  |  |  |  |  |  | 0 | 0
 |  |  |  |  |  |  |  |  | 0 | 0
 |  |  |  |  |  |  |  |  | 0 | 0
 |  |  |  |  |  |  |  |  | 0 | 0
 |  |  |  |  |  |  |  |  | 0 | 0
 |  |  |  |  |  |  |  |  | 0 | 0
 |  |  |  |  |  |  |  |  | 0 | 0
 |  |  |  |  |  |  |  |  | 0 | 0
 |  |  |  |  |  |  |  |  | 0 | 0
 |  |  |  |  |  |  |  |  | 0 | 0
 |  |  |  |  |  |  |  |  | 0 | 0
 |  |  |  |  |  |  |  |  | 0 | 0
 |  |  |  |  |  |  |  |  | 0 | 0
 |  |  |  |  |  |  |  |  | 0 | 0
 |  |  |  |  |  |  |  |  | 0 | 0
 |  |  |  |  |  |  |  |  | 0 | 0
 |  |  |  |  |  |  |  |  | 0 | 0
 |  |  |  |  |  |  |  |  | 0 | 0
 |  |  |  |  |  |  |  |  | 0 | 0
 |  |  |  |  |  |  |  |  | 0 | 0
 |  |  |  |  |  |  |  |  | 0 | 0
 |  |  |  |  |  |  |  |  | 0 | 0
 |  |  |  |  |  |  |  |  | 0 | 0
 |  |  |  |  |  |  |  |  | 0 | 0
 |  |  |  |  |  |  |  |  | 0 | 0
 |  |  |  |  |  |  |  |  | 0 | 0
 |  |  |  |  |  |  |  |  | 0 | 0
 |  |  |  |  |  |  |  |  | 0 | 0
 |  |  |  |  |  |  |  |  | 0 | 0
 |  |  |  |  |  |  |  |  | 0 | 0
 |  |  |  |  |  |  |  |  | 0 | 0
 |  |  |  |  |  |  |  |  | 0 | 0
 |  |  |  |  |  |  |  |  | 0 | 0
 |  |  |  |  |  |  |  |  | 0 | 0
 |  |  |  |  |  |  |  |  | 0 | 0
 |  |  |  |  |  |  |  |  | 0 | 0
 |  |  |  |  |  |  |  |  | 0 | 0
 |  |  |  |  |  |  |  |  | 0 | 0
 |  |  |  |  |  |  |  |  | 0 | 0
 |  |  |  |  |  |  |  |  | 0 | 0
 |  |  |  |  |  |  |  |  | 0 | 0
 |  |  |  |  |  |  |  |  | 0 | 0
 |  |  |  |  |  |  |  |  | 0 | 0
 |  |  |  |  |  |  |  |  | 0 | 0
 |  |  |  |  |  |  |  |  | 0 | 0
 |  |  |  |  |  |  |  |  | 0 | 0
 |  |  |  |  |  |  |  |  | 0 | 0
 |  |  |  |  |  |  |  |  | 0 | 0
 |  |  |  |  |  |  |  |  | 0 | 0
 |  |  |  |  |  |  |  |  | 0 | 0
 |  |  |  |  |  |  |  |  | 0 | 0
 |  |  |  |  |  |  |  |  | 0 | 0
 |  |  |  |  |  |  |  |  | 0 | 0
 |  |  |  |  |  |  |  |  | 0 | 0
 |  |  |  |  |  |  |  |  | 0 | 0
 |  |  |  |  |  |  |  |  | 0 | 0
 |  |  |  |  |  |  |  |  | 0 | 0
 |  |  |  |  |  |  |  |  | 0 | 0
 |  |  |  |  |  |  |  |  | 0 | 0
 |  |  |  |  |  |  |  |  | 0 | 0
 |  |  |  |  |  |  |  |  | 0 | 0
 |  |  |  |  |  |  |  |  | 0 | 0
 |  |  |  |  |  |  |  |  | 0 | 0
 |  |  |  |  |  |  |  |  | 0 | 0
 |  |  |  |  |  |  |  |  | 0 | 0
 |  |  |  |  |  |  |  |  | 0 | 0
 |  |  |  |  |  |  |  |  | 0 | 0
 |  |  |  |  |  |  |  |  | 0 | 0
 |  |  |  |  |  |  |  |  | 0 | 0
 |  |  |  |  |  |  |  |  | 0 | 0
 |  |  |  |  |  |  |  |  | 0 | 0
 |  |  |  |  |  |  |  |  | 0 | 0
 |  |  |  |  |  |  |  |  | 0 | 0
 |  |  |  |  |  |  |  |  | 0 | 0
 |  |  |  |  |  |  |  |  | 0 | 0
 |  |  |  |  |  |  |  |  | 0 | 0
 |  |  |  |  |  |  |  |  | 0 | 0
 |  |  |  |  |  |  |  |  | 0 | 0
 |  |  |  |  |  |  |  |  | 0 | 0
 |  |  |  |  |  |  |  |  | 0 | 0
 |  |  |  |  |  |  |  |  | 0 | 0
 |  |  |  |  |  |  |  |  | 0 | 0
 |  |  |  |  |  |  |  |  | 0 | 0
 |  |  |  |  |  |  |  |  | 0 | 0
 |  |  |  |  |  |  |  |  | 0 | 0
 |  |  |  |  |  |  |  |  | 0 | 0
 |  |  |  |  |  |  |  |  | 0 | 0
 |  |  |  |  |  |  |  |  | 0 | 0
 |  |  |  |  |  |  |  |  | 0 | 0
 |  |  |  |  |  |  |  |  | 0 | 0
 |  |  |  |  |  |  |  |  | 0 | 0
 |  |  |  |  |  |  |  |  | 0 | 0
 |  |  |  |  |  |  |  |  | 0 | 0
 |  |  |  |  |  |  |  |  | 0 | 0
 |  |  |  |  |  |  |  |  | 0 | 0
 |  |  |  |  |  |  |  |  | 0 | 0
 |  |  |  |  |  |  |  |  | 0 | 0
 |  |  |  |  |  |  |  |  | 0 | 0
 |  |  |  |  |  |  |  |  | 0 | 0
 |  |  |  |  |  |  |  |  | 0 | 0
 |  |  |  |  |  |  |  |  | 0 | 0
 |  |  |  |  |  |  |  |  | 0 | 0
 |  |  |  |  |  |  |  |  | 0 | 0
 |  |  |  |  |  |  |  |  | 0 | 0
 |  |  |  |  |  |  |  |  | 0 | 0
 |  |  |  |  |  |  |  |  | 0 | 0
 |  |  |  |  |  |  |  |  | 0 | 0
 |  |  |  |  |  |  |  |  | 0 | 0
 |  |  |  |  |  |  |  |  | 0 | 0
 |  |  |  |  |  |  |  |  | 0 | 0
 |  |  |  |  |  |  |  |  | 0 | 0
 |  |  |  |  |  |  |  |  | 0 | 0
 |  |  |  |  |  |  |  |  | 0 | 0
 |  |  |  |  |  |  |  |  | 0 | 0
 |  |  |  |  |  |  |  |  | 0 | 0
 |  |  |  |  |  |  |  |  | 0 | 0
 |  |  |  |  |  |  |  |  | 0 | 0
 |  |  |  |  |  |  |  |  | 0 | 0
 |  |  |  |  |  |  |  |  | 0 | 0
 |  |  |  |  |  |  |  |  | 0 | 0
 |  |  |  |  |  |  |  |  | 0 | 0
 |  |  |  |  |  |  |  |  | 0 | 0
 |  |  |  |  |  |  |  |  | 0 | 0
 |  |  |  |  |  |  |  |  | 0 | 0
 |  |  |  |  |  |  |  |  | 0 | 0
 |  |  |  |  |  |  |  |  | 0 | 0
 |  |  |  |  |  |  |  |  | 0 | 0
 |  |  |  |  |  |  |  |  | 0 | 0
 |  |  |  |  |  |  |  |  | 0 | 0
 |  |  |  |  |  |  |  |  | 0 | 0
 |  |  |  |  |  |  |  |  | 0 | 0
 |  |  |  |  |  |  |  |  | 0 | 0
 |  |  |  |  |  |  |  |  | 0 | 0
 |  |  |  |  |  |  |  |  | 0 | 0
 |  |  |  |  |  |  |  |  | 0 | 0
 |  |  |  |  |  |  |  |  | 0 | 0
 |  |  |  |  |  |  |  |  | 0 | 0
 |  |  |  |  |  |  |  |  | 0 | 0
 |  |  |  |  |  |  |  |  | 0 | 0
 |  |  |  |  |  |  |  |  | 0 | 0
 |  |  |  |  |  |  |  |  | 0 | 0
 |  |  |  |  |  |  |  |  | 0 | 0
 |  |  |  |  |  |  |  |  | 0 | 0
 |  |  |  |  |  |  |  |  | 0 | 0
 |  |  |  |  |  |  |  |  | 0 | 0
 |  |  |  |  |  |  |  |  | 0 | 0
 |  |  |  |  |  |  |  |  | 0 | 0
 |  |  |  |  |  |  |  |  | 0 | 0
 |  |  |  |  |  |  |  |  | 0 | 0
 |  |  |  |  |  |  |  |  | 0 | 0
 |  |  |  |  |  |  |  |  | 0 | 0
 |  |  |  |  |  |  |  |  | 0 | 0
 |  |  |  |  |  |  |  |  | 0 | 0
 |  |  |  |  |  |  |  |  | 0 | 0
 |  |  |  |  |  |  |  |  | 0 | 0
 |  |  |  |  |  |  |  |  | 0 | 0
 |  |  |  |  |  |  |  |  | 0 | 0
 |  |  |  |  |  |  |  |  | 0 | 0
 |  |  |  |  |  |  |  |  | 0 | 0
 |  |  |  |  |  |  |  |  | 0 | 0
 |  |  |  |  |  |  |  |  | 0 | 0
 |  |  |  |  |  |  |  |  | 0 | 0
 |  |  |  |  |  |  |  |  | 0 | 0
 |  |  |  |  |  |  |  |  | 0 | 0
 |  |  |  |  |  |  |  |  | 0 | 0
 |  |  |  |  |  |  |  |  | 0 | 0
 |  |  |  |  |  |  |  |  | 0 | 0
 |  |  |  |  |  |  |  |  | 0 | 0
 |  |  |  |  |  |  |  |  | 0 | 0
 |  |  |  |  |  |  |  |  | 0 | 0
 |  |  |  |  |  |  |  |  | 0 | 0
 |  |  |  |  |  |  |  |  | 0 | 0
 |  |  |  |  |  |  |  |  | 0 | 0
 |  |  |  |  |  |  |  |  | 0 | 0
 |  |  |  |  |  |  |  |  | 0 | 0
 |  |  |  |  |  |  |  |  | 0 | 0
 |  |  |  |  |  |  |  |  | 0 | 0
 |  |  |  |  |  |  |  |  | 0 | 0
 |  |  |  |  |  |  |  |  | 0 | 0
 |  |  |  |  |  |  |  |  | 0 | 0
 |  |  |  |  |  |  |  |  | 0 | 0
 |  |  |  |  |  |  |  |  | 0 | 0
 |  |  |  |  |  |  |  |  | 0 | 0
 |  |  |  |  |  |  |  |  | 0 | 0
 |  |  |  |  |  |  |  |  | 0 | 0
 |  |  |  |  |  |  |  |  | 0 | 0
 |  |  |  |  |  |  |  |  | 0 | 0
 |  |  |  |  |  |  |  |  | 0 | 0
 |  |  |  |  |  |  |  |  | 0 | 0
 |  |  |  |  |  |  |  |  | 0 | 0
 |  |  |  |  |  |  |  |  | 0 | 0
 |  |  |  |  |  |  |  |  | 0 | 0
 |  |  |  |  |  |  |  |  | 0 | 0
 |  |  |  |  |  |  |  |  | 0 | 0
 |  |  |  |  |  |  |  |  | 0 | 0
 |  |  |  |  |  |  |  |  | 0 | 0
 |  |  |  |  |  |  |  |  | 0 | 0
 |  |  |  |  |  |  |  |  | 0 | 0
 |  |  |  |  |  |  |  |  | 0 | 0
 |  |  |  |  |  |  |  |  | 0 | 0
 |  |  |  |  |  |  |  |  | 0 | 0
 |  |  |  |  |  |  |  |  | 0 | 0
 |  |  |  |  |  |  |  |  | 0 | 0
 |  |  |  |  |  |  |  |  | 0 | 0
 |  |  |  |  |  |  |  |  | 0 | 0
 |  |  |  |  |  |  |  |  | 0 | 0
 |  |  |  |  |  |  |  |  | 0 | 0
 |  |  |  |  |  |  |  |  | 0 | 0
 |  |  |  |  |  |  |  |  | 0 | 0
 |  |  |  |  |  |  |  |  | 0 | 0
 |  |  |  |  |  |  |  |  | 0 | 0
 |  |  |  |  |  |  |  |  | 0 | 0
 |  |  |  |  |  |  |  |  | 0 | 0
 |  |  |  |  |  |  |  |  | 0 | 0
 |  |  |  |  |  |  |  |  | 0 | 0
 |  |  |  |  |  |  |  |  | 0 | 0
 |  |  |  |  |  |  |  |  | 0 | 0
 |  |  |  |  |  |  |  |  | 0 | 0
 |  |  |  |  |  |  |  |  | 0 | 0
 |  |  |  |  |  |  |  |  | 0 | 0
 |  |  |  |  |  |  |  |  | 0 | 0
 |  |  |  |  |  |  |  |  | 0 | 0
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

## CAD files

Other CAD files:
Software/msp430DisassemblerTest/DebugG2553/main.obj
Software/msp430DisplayDriverTest/DebugG2553/main.obj
Software/msp430DisassemblerTest/DebugG2553/tests/integration_tests.obj

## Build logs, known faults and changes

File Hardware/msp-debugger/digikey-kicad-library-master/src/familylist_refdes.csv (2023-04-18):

205 | Embedded - Microcontrollers | U
275 | Motion Sensors - Accelerometers | U
1152 | Magnetic Sensors - Linear, Compass (ICs) | U
69 | TVS - Diodes | D
19 | Fixed Inductors | L
793 | Interface - Controllers | U
1373 | PMIC - Battery Chargers | U
748 | Optical Sensors - Ambient Light, IR, UV Sensors | U
366 | Oscillators | Y
707 | RF Detectors | U
446 | Data Acquisition - Digital Potentiometers | U
533 | Logic - Translators, Level Shifters | U
1324 | Diodes - Bridge Rectifiers | D
740 | USB, DVI, HDMI Connectors | J
1379 | Motion Sensors - IMUs (Inertial Measurement Units) | U
1303 | Barrel - Audio Connectors | CON
628 | Humidity, Moisture Sensors | U
51 | Encoders | S
71 | Alarms, Buzzers, and Sirens | BZ
94 | Tactile Switches | S
968 | Optical Sensors - Photodiodes | PV
120 | Transistors - Bipolar (BJT) - Single | Q
706 | Transistors - Bipolar (BJT) - RF | Q
386 | PMIC - Voltage Regulators - Linear | U
72 | Microphones | MIC
872 | Signal Relays, Up to 2 Amps | RLY
1193 | Memory Connectors - PC Card Sockets | J
40 | Infrared, UV, Visible Emitters | D
655 | Gas Sensors | U
973 | Optical Sensors - Photointerrupters - Slot Type - Logic Output | U
61 | Fuses | F
125 | Transistors - FETs, MOSFETs - Single | Q
79 | Programmable Oscillators | Y
311 | Temperature Sensors - Analog and Digital Output | U
1398 | Automotive Relays | RLY
1400 | Reed Relays | RLY
421 | Logic - Multivibrators | U
127 | Diodes - Rectifiers - Single | D
778 | Diodes - Zener - Single | Z
758 | Diodes - Rectifiers - Arrays | D
210 | Specialized ICs | U
293 | PMIC - Supervisors | U
319 | PMIC - Voltage Reference | VR
747 | Transistors - FETs, MOSFETs - RF | Q
1010 | Transistors - Bipolar (BJT) - Single, Pre-Biased | Q
544 | PMIC - Current Regulation/Management | U
804 | PMIC - Power Management - Specialized | U
1004 | RF Transceiver Modules | MOD
838 | Transistors - FETs, MOSFETs - Arrays | Q
404 | Logic - Buffers, Drivers, Receivers, Transceivers | U
711 | RF Switches | U
122 | Transistors - Bipolar (BJT) - Arrays | Q
1281 | Slide Switches | S
413 | Logic - Gates and Inverters | U
502 | PMIC - Power Distribution Switches, Load Drivers | U
523 | PMIC - Gate Drivers | U
221 | Linear - Amplifiers - Instrumentation, OP Amps, Buffer Amps | U
317 | Linear - Comparators | U
724 | PMIC - LED Drivers | U
388 | Data Acquisition - Digital to Analog Converters (DAC) | U
666 | PMIC - Voltage Regulators - DC DC Switching Regulators | U
865 | TVS - Mixed Technology | TVS
700 | RF Evaluation and Development Kits, Boards | A
1344 | Rotary Potentiometers, Rheostats | POT
871 | Power Relays, Over 2 Amps | RLY
948 | Modular Connectors - Jacks | J
1306 | Coaxial Connectors (RF) | J
944 | Optical Sensors - Photo Detectors - Remote Receiver | U
683 | Ferrite Beads and Chips | FB
441 | LED Indication - Discrete | D
969 | Optical Sensors - Phototransistors | Q
674 | Image Sensors, Camera | U
420 | Interface - Drivers, Receivers, Transceivers | U
100 | Toggle Switches | S
36 | Display Modules - LED Character and Numeric | DS
387 | Data Acquisition - Analog to Digital Converters (ADC) | U
517 | Clock/Timing - Clock Generators, PLLs, Frequency Synthesizers | U
432 | PMIC - Battery Management | U
34 | Battery Holders, Clips, Contacts | BAT
1127 | Surge Suppression ICs | U
438 | PMIC - Voltage Regulators - DC DC Switching Controllers | U
656 | PMIC - Thermal Management | U
1370 | Interface - Analog Switches - Special Purpose | U
789 | PMIC - Voltage Regulators - Special Purpose | U
728 | PMIC - Full, Half-Bridge Drivers | U
422 | Logic - Shift Registers | U
515 | PMIC - V/F and F/V Converters | U
414 | Logic - Flip Flops | U
679 | Linear - Amplifiers - Audio | U
722 | PMIC - Motor Drivers, Controllers | U
767 | Interface - Analog Switches, Multiplexers, Demultiplexers | U
831 | Optoisolators - Transistor, Photovoltaic Output | U
786 | Interface - I/O Expanders | U
1002 | RF Receivers | U
1349 | RF Transceiver ICs | U
691 | Logic - Signal Switches, Multiplexers, Decoders | U
1357 | RFID, RF Access, Monitoring ICs | U
88 | Solid State Relays | RLY
972 | Optical Sensors - Reflective - Analog Output | U
829 | Optoisolators - Logic Output | U
842 | Optoisolators - Triac, SCR Output | U
75 | Balun | T
226 | Clock/Timing - Programmable Timers and Oscillators | U
266 | Clock/Timing - Real Time Clocks | U
668 | PMIC - RMS to DC Converters | U
179 | Pressure Sensors, Transducers | U
552 | Digital Isolators | U
792 | Interface - Sensor and Detector Interfaces | U
1076 | Memory | U
493 | Current Transducers | U
768 | PMIC - AC DC Converters, Offline Switchers | U
800 | PMIC - OR Controllers, Ideal Diodes | Q
7 | Resistor Networks, Arrays | RN
64 | Thyristors - DIACs, SIDACs | D
97 | Pushbutton Switches | S
1140 | Magnetic Sensors - Compass, Magnetic Field (Modules) | U
725 | Navigation Switches, Joystick | S
336 | Thermal Cutoffs (Thermal Fuses) | F
448 | LEDs - Circuit Board Indicators, Arrays, Light Bars, Bar Graphs | D
1315 | Specialized Sensors | U
84 | Accessories | NA
824 | Trimmer Potentiometers | POT
131 | Thyristors - SCRs | D
1325 | Thyristors - TRIACs | TRI
1366 | Magnetic Sensors - Switches (Solid State) | Q
837 | Transistors - JFETs | Q
1003 | RF Transmitters | U
1360 | Addressable, Specialty | D
755 | Rectangular Connectors - Headers, Male Pins | J
947 | Modular Connectors - Jacks With Magnetics | J
913 | Inrush Current Limiters (ICL) | ICL
1230 | Data Acquisition - Touch Screen Controllers | U
1293 | Capacitive Touch Sensors, Proximity Sensor ICs | U
1176 | RF Demodulators | U
223 | DC DC Converters | U
461 | Motion Sensors - Tilt Switches | S
864 | Data Acquisition - ADCs/DACs - Special Purpose | U
1295 | Interface - Modules | U
703 | RF Amplifiers | U
1078 | RF Antennas | ANT
1180 | Sockets for ICs, Transistors | J
1308 | D-Sub Connectors | J
794 | Interface - Specialized | U
1117 | Evaluation Boards - Sensors | A
333 | Evaluation Boards - Embedded - MCU, DSP | A
630 | Display Modules - LCD, OLED, Graphic | DS
365 | Crystal | XTAL
135 | Banana and Tip Connectors - Jacks, Plugs | J
1304 | Barrel - Power Connectors | J
946 | Optical Sensors - Distance Measuring | U
168 | Shunts, Jumpers | J
586 | Test Points | TP
959 | Terminal Blocks - Wire to Board | J

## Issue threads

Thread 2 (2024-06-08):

Display is not large enough to handle lines of 30 characters.

jdbaptista, 2024-06-08:
30 characters is the maximum number of characters of one line of assembly produced by the disassembler. This can be reduced to 28 if necessary by using FFFFh instead of 0xFFFF format. The maximum length assembly instruction would be a length 4 double format operation with two indexed operands, such as ADDC.W 0xFFFF(R5) OxFFFF(R7).

jdbaptista, 2024-06-23:
Fixed in commit a686eec, however a new issues, #7, has arisen.

Closed 2024-06-23.

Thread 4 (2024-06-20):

USB to UART bridge has an incorrect footprint size.

jdbaptista, 2024-06-20:

jdbaptista, 2024-06-27:
Fixed in 4347ad7.

Closed 2024-06-27.

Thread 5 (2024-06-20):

Cannot use MSP-FET without two USB cables.

jdbaptista, 2024-06-20:
The JTAG access connector, J4, does not include ground and power lines, so a USB cable must be connected to the MSP-FET alongside a USB cable connected to the PCB to supply power.

jdbaptista, 2024-06-27:
Fixed in 4347ad7. A header was added with silkscreen pinout instructions, along with jumpers to disconnect USB lines.

Closed 2024-06-27.

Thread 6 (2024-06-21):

Target RESET pin is floating.

jdbaptista, 2024-06-21:
Workaround is to bring it high by connecting it to 3.3v on the target pinout header.

jdbaptista, 2024-06-21:
The MSP430 JTAG programming guide contains Figure 2-13 shows that in both cases the JTAG entry sequence requires a toggle on RST. Unless SBW is implemented, RST needs to be connected to a pin on the controller.

jdbaptista, 2024-06-27:
Fixed in 4347ad7.

Closed 2024-06-27.

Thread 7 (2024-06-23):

Display logic runs on 5v, not 3.3v.

jdbaptista, 2024-06-23:

jdbaptista, 2024-06-27:
Since 4347ad7, 3.3V data lines are used as gate inputs to MOSFETS that send 5V to display data lines. Display data lines are pulled low by 10K resistors.

Closed 2024-06-27.

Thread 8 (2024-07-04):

Button footprints are incorrect.

jdbaptista, 2024-07-04:
They should be rotated by 90 degrees with respect to the pinout. The buttons are actually rectangular, not square, which causes issues. A workaround is to bend the pins into the correct positions when installing.

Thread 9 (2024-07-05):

Mosfet source pins should be grounded.

jdbaptista, 2024-07-05:
The output of the mosfets, currently the source pin, is only outputting 1.4v instead of 5v because the gate voltage is relative to the source pin, not the drain pin. This means that when the transistor turns on it immediately turns off because the source goes to 5v and Vgs subsequently goes to -2v and turns off. This is problematic and means that the display will not work without changes to the circuit and pcb. :(

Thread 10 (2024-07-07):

Add support for follow jump button on CALL instructions.

jdbaptista, 2024-07-07:

jdbaptista, 2024-07-17:
Support for this is problematic because the instruction, CALL dst, evaluates dst as a regular operand. Therefore, it is hard without simulation to determine dst unless the addressing mode is symbolic mode (PC relative immediate), immediate mode, or potentially absolute mode when it is known that the address has a constant value in flash memory.

jdbaptista, 2024-07-17:
Realistic support added in [c55bcd3](https://github.com/jdbaptista/MSP-Debugger/commit/c55bcd36799663f51a06ee84e6d338690573d007).

Closed 2024-07-17.

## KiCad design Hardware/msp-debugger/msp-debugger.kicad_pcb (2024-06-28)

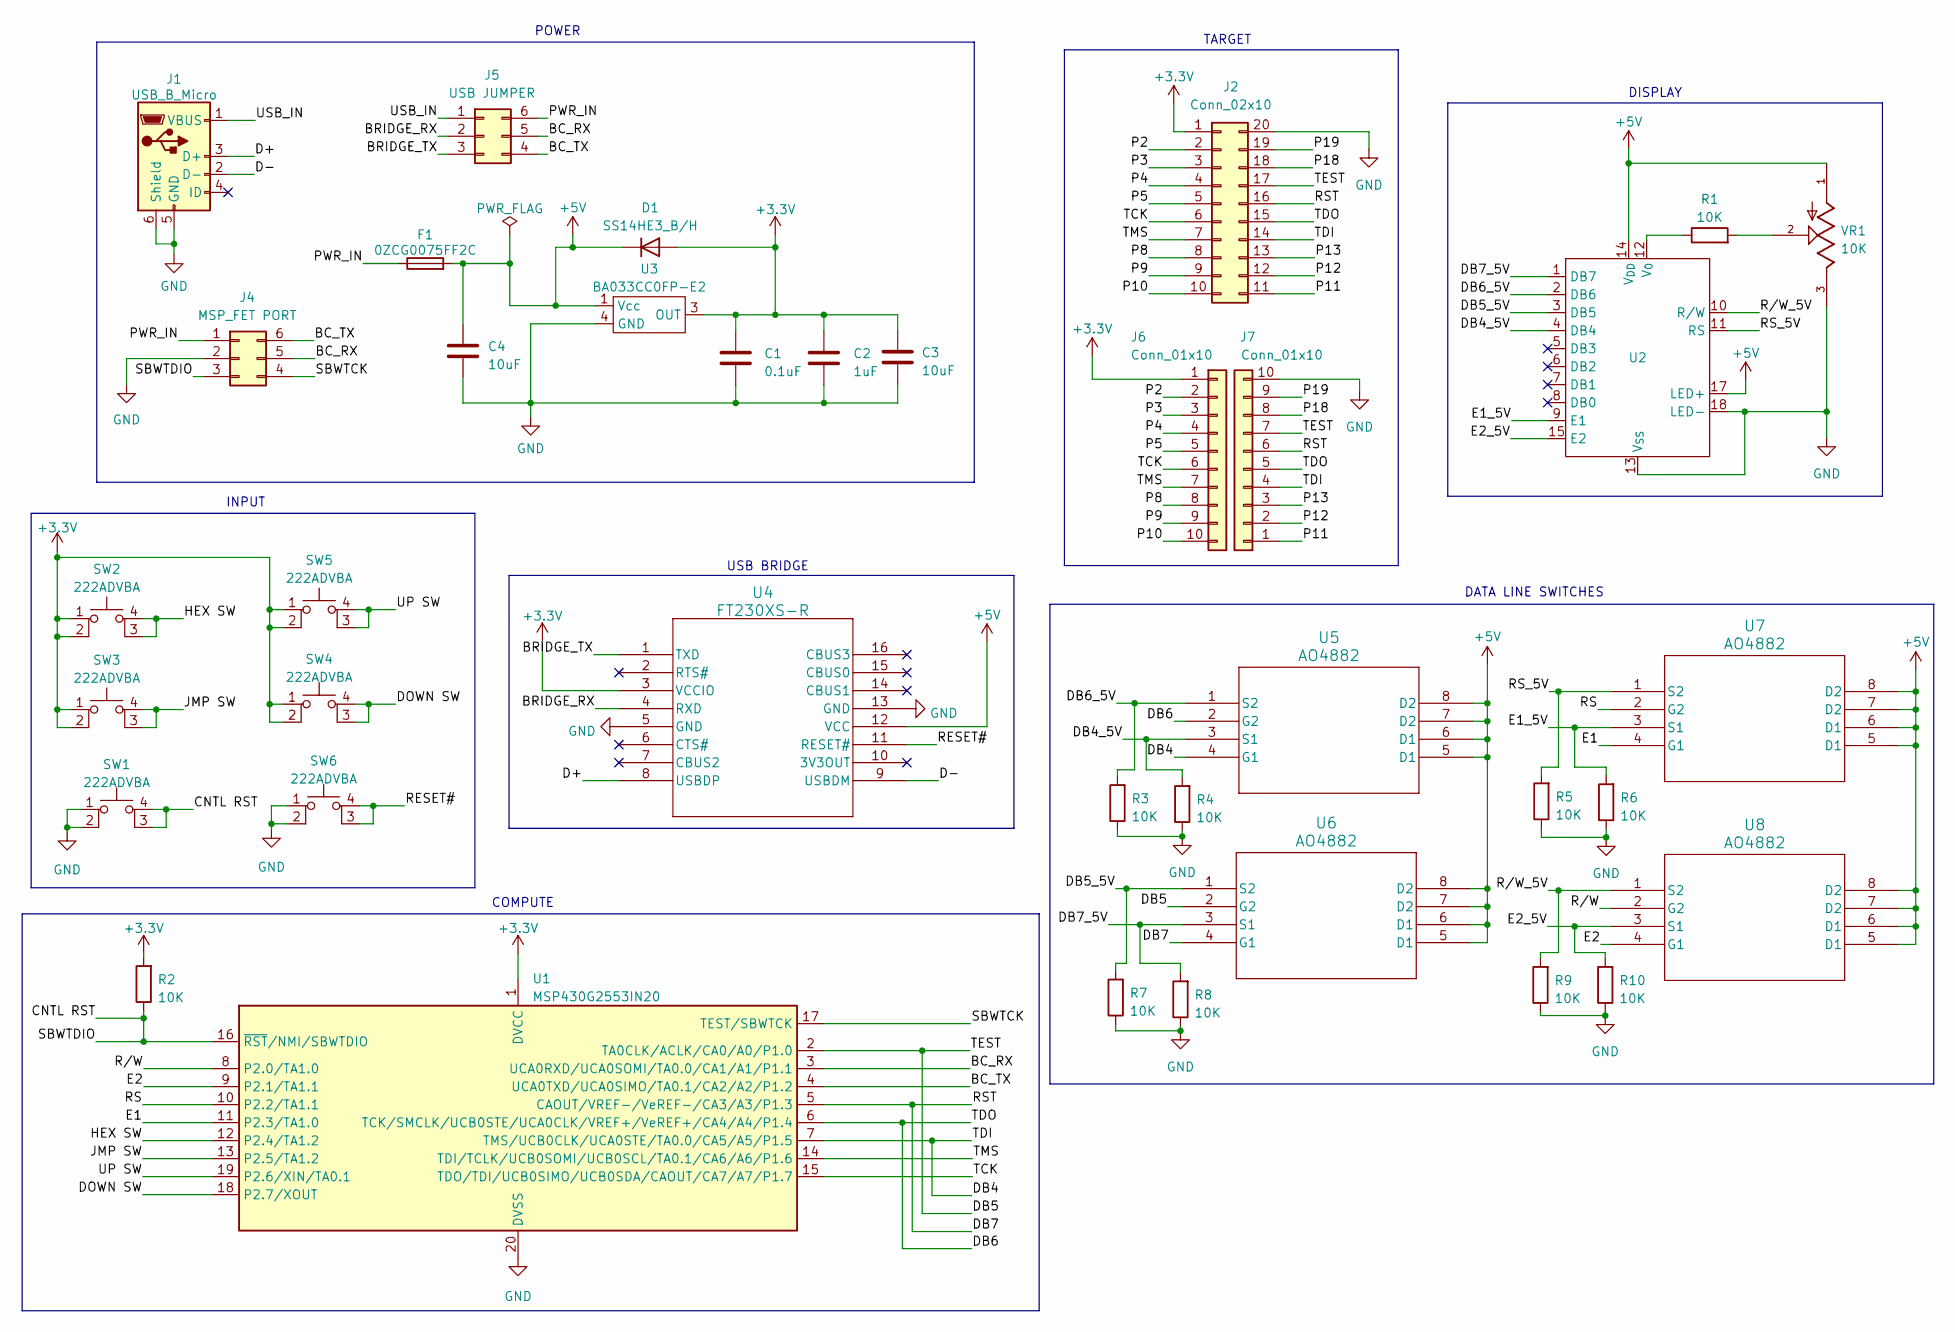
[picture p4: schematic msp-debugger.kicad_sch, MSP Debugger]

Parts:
C1: 0.1uF; C_0805_2012Metric
C2: 1uF; C_0805_2012Metric
C3, C4: 10uF; C_0805_2012Metric
D1: SS14HE3_B/H; D_SMA
F1: 0ZCG0075FF2C; Fuse_1812_4532Metric
J1: USB_B_Micro; PinHeader_1x05_P2.54mm_Vertical
J2: Conn_02x10; DIL_CONN_110-83-320-41-001101
J4: MSP_FET PORT; PinHeader_2x03_P2.54mm_Vertical
J5: USB JUMPER; PinHeader_2x03_P2.54mm_Vertical
J6, J7: Conn_01x10; PinHeader_1x10_P2.54mm_Vertical
R1, R2, R3, R4, R5, R6, R7, R8, R9, R10: 10K; C_0805_2012Metric
SW1, SW2, SW3, SW4, SW5, SW6: 222ADVBA; SW_222ADVBA
U1: MSP430G2553IN20; DIP-20_W7.62mm
U2: PinHeader_2x09_P2.54mm_Vertical
U3: BA033CC0FP-E2; TO-252-3
U4: FT230XS-R; SOIC_30XS-R_FTD
U5, U6, U7, U8: AO4882; SO-8_AOS
VR1: 10K; TRIM_3362P-1-103LF; PARTREV 08/26/10

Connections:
+3.3V: C1.2, C2.1, C3.1, D1.2 (A), J2.1, J6.1, R2.2, SW2.1, SW2.2, SW3.1, SW3.2, SW4.1, SW4.2, SW5.1, SW5.2, U1.1 (DVCC), U3.3 (OUT), U4.3 (VCCIO)
+5V: C4.1, D1.1 (K), F1.2, U2.14 (V_{DD}), U2.17 (LED+), U3.1 (Vcc), U4.12 (VCC), U5.5 (D1), U5.6 (D1), U5.7 (D2), U5.8 (D2), U6.5 (D1), U6.6 (D1), U6.7 (D2), U6.8 (D2), U7.5 (D1), U7.6 (D1), U7.7 (D2), U7.8 (D2), U8.5 (D1), U8.6 (D1), U8.7 (D2), U8.8 (D2), VR1.1
/BC_RX: J4.5, J5.5, U1.3 (UCA0RXD/UCA0SOMI/TA0.0/CA1/A1/P1.1)
/BC_TX: J4.6, J5.4, U1.4 (UCA0TXD/UCA0SIMO/TA0.1/CA2/A2/P1.2)
/BRIDGE_RX: J5.2, U4.4 (RXD)
/BRIDGE_TX: J5.3, U4.1 (TXD)
/CNTL RST: J4.3, R2.1, SW1.3 (K), SW1.4 (A), U1.16 (~RST/NMI/SBWTDIO)
/D+: J1.3 (D+), U4.8 (USBDP)
/D-: J1.2 (D-), U4.9 (USBDM)
/DB4: J2.14, J7.4, U1.7 (TMS/UCB0CLK/UCA0STE/TA0.0/CA5/A5/P1.5), U5.4 (G1)
/DB4_5V: R4.2, U2.4 (DB4), U5.3 (S1)
/DB5: J2.17, J7.7, U1.2 (TA0CLK/ACLK/CA0/A0/P1.0), U6.2 (G2)
/DB5_5V: R7.2, U2.3 (DB5), U6.1 (S2)
/DB6: J2.15, J7.5, U1.6 (TCK/SMCLK/UCB0STE/UCA0CLK/VREF+/VeREF+/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), U5.2 (G2)
/DB6_5V: R3.2, U2.2 (DB6), U5.1 (S2)
/DB7: J2.16, J7.6, U1.5 (CAOUT/VREF-/VeREF-/CA3/A3/P1.3), U6.4 (G1)
/DB7_5V: R8.2, U2.1 (DB7), U6.3 (S1)
/DOWN SW: SW4.3 (K), SW4.4 (A), U1.18 (P2.7/XOUT)
/E1: U1.11 (P2.3/TA1.0), U7.4 (G1)
/E1_5V: R6.2, U2.9 (E1), U7.3 (S1)
/E2: U1.9 (P2.1/TA1.1), U8.4 (G1)
/E2_5V: R10.2, U2.15 (E2), U8.3 (S1)
/HEX SW: SW2.3 (K), SW2.4 (A), U1.12 (P2.4/TA1.2)
/JMP SW: SW3.3 (K), SW3.4 (A), U1.13 (P2.5/TA1.2)
/P2: J2.2, J6.2
/P3: J2.3, J6.3
/P4: J2.4, J6.4
/P5: J2.5, J6.5
/P8: J2.8, J6.8
/P9: J2.9, J6.9
/P10: J2.10, J6.10
/P11: J2.11, J7.1
/P12: J2.12, J7.2
/P13: J2.13, J7.3
/P18: J2.18, J7.8
/P19: J2.19, J7.9
/PWR_IN: F1.1, J4.1, J5.6
/RESET#: SW6.3 (K), SW6.4 (A), U4.11 (RESET#)
/RS: U1.10 (P2.2/TA1.1), U7.2 (G2)
/RS_5V: R5.2, U2.11 (RS), U7.1 (S2)
/R/W: U1.8 (P2.0/TA1.0), U8.2 (G2)
/R/W_5V: R9.2, U2.10 (R/W), U8.1 (S2)
/SBWTCK: J4.4, U1.17 (TEST/SBWTCK)
/TCK: J2.6, J6.6, U1.15 (TDO/TDI/UCB0SIMO/UCB0SDA/CAOUT/CA7/A7/P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)
/TMS: J2.7, J6.7, U1.14 (TDI/TCLK/UCB0SOMI/UCB0SCL/TA0.1/CA6/A6/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)
/UP SW: SW5.3 (K), SW5.4 (A), U1.19 (P2.6/XIN/TA0.1)
/USB_IN: J1.1 (VBUS), J5.1
GND: C1.1, C2.2, C3.2, C4.2, J1.5 (GND), J1.6 (Shield), J2.20, J4.2, J7.10, R3.1, R4.1, R5.1, R6.1, R7.1, R8.1, R9.1, R10.1, SW1.1, SW1.2, SW6.1, SW6.2, U1.20 (DVSS), U2.13 (V_{SS}), U2.18 (LED-), U3.4 (GND), U4.5 (GND), U4.13 (GND), VR1.3
unnamed: R1.2, VR1.2
unnamed: R1.1, U2.12 (V_{0})

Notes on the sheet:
POWER
DATA LINE SWITCHES
USB BRIDGE
INPUT
COMPUTE
TARGET
DISPLAY

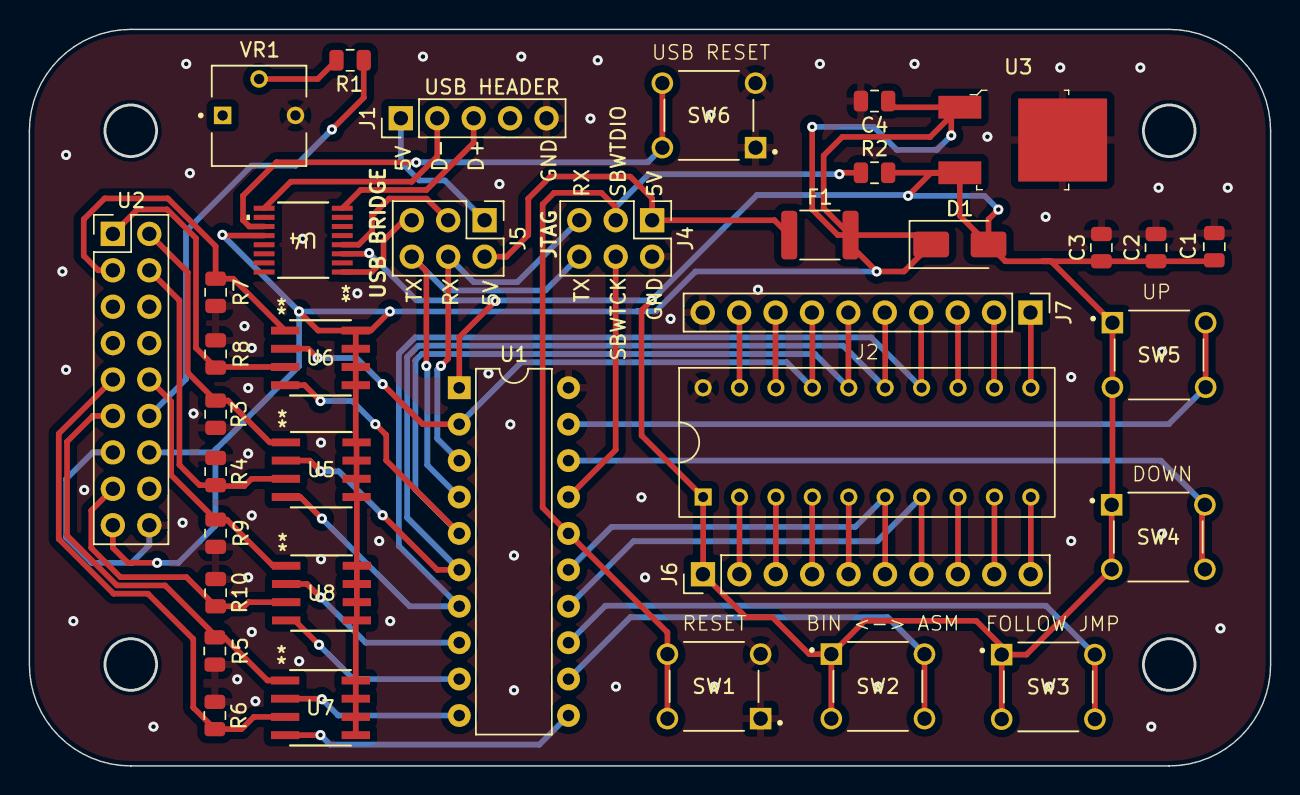
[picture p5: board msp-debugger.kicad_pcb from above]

Board: 2 copper layers, 86.6 x 51.4 mm, 37 parts (0 on the bottom side), 50 nets.

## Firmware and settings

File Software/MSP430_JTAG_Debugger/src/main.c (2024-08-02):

#include <msp430.h>
#include <jtag_fsm.h>
#include <stdlib.h>
#include <stdint.h>
#include <stdbool.h>
#include "bc_uart.h"
#include "jtag_fsm.h"
#include "jtag_control.h"
#include "disassembler.h"
#include "buttons.h"

#pragma vector=BTN_VECT
interrupt void buttonIRQ(void) {
    __bic_SR_register(GIE);
    __bis_SR_register_on_exit(GIE);
    if (BTN_IFG & HEX_BTN_IFG) {
        setButtonLatch(SHOW_BTN);
        BTN_IFG &= ~HEX_BTN_IFG;
    } else if (BTN_IFG & JMP_BTN_IFG) {
        setButtonLatch(JUMP_BTN);
        BTN_IFG &= ~JMP_BTN_IFG;
    } else if (BTN_IFG & DOWN_BTN_IFG) {
        setButtonLatch(DOWN_BTN);
        BTN_IFG &= ~DOWN_BTN_IFG;
    } else if (BTN_IFG & UP_BTN_IFG) {
        setButtonLatch(UP_BTN);
        BTN_IFG &= ~UP_BTN_IFG;
    } else {
        BTN_IFG &= ~BUTTONS;
    }
    return;
}

#pragma vector=TIMER0_A1_VECTOR
interrupt void timerDebounceIRQ(void) {
    __bic_SR_register(GIE);
    __bis_SR_register_on_exit(GIE);
    bool update = false;

    if (TA0IV & TA0IV_TAIFG != TA0IV_TAIFG) {
        return; // automatically removes highest ifg
    }
    update = updateButton(JUMP_BTN);
    update |= updateButton(UP_BTN);
    update |= updateButton(DOWN_BTN);
    // update latch button with a special cmd
    if (isButtonLatchSet(SHOW_BTN)) {
        clrButtonLatch(SHOW_BTN);
        setButtonWait(SHOW_BTN);
    } else if (isButtonWaitSet(SHOW_BTN)) {
        // XOR (toggle) the show button
        if (isButtonCmdSet(SHOW_BTN)) {
            clrButtonCmd(SHOW_BTN);
        } else {
            setButtonCmd(SHOW_BTN);
        }
        clrButtonWait(SHOW_BTN);
        update = true;
    }
    // return to Active Mode if an update should occur
    if (update) {
        __bic_SR_register_on_exit(SCG0 | SCG1 | CPUOFF);
    }
    TA0IV = 0;
}

inline void initButtons() {
    // clear button debouncing logic flags
    clrButtons();

    // set GPIO pin registers for buttons
    BTN_SEL &= ~BUTTONS;
    BTN_SEL2 &= ~BUTTONS;
    BTN_OUT &= ~BUTTONS;
    BTN_IN &= ~BUTTONS;
    BTN_REN |= BUTTONS;
    BTN_DIR &= ~BUTTONS;
    BTN_IES &= ~BUTTONS;
    BTN_IFG &= ~BUTTONS;
    BTN_IE |= BUTTONS;

    // setup timer A0 for debouncing
    BCSCTL3 &= ~BIT4; // source ACLK from VLOCLK (12kHz)
    BCSCTL3 |= BIT5;
    TA0CTL &= ~TASSEL1; // select ACLK source
    TA0CTL |= TASSEL0;
    TA0CTL |= ID0; // select input divider 2
    TA0CTL &= ~ID1;
    TACCR0 = 0x02FF; // set the value to count up to
                     // manually calibrated to remove debouncing
    TA0CTL &= ~MC1; // select up mode
    TA0CTL |= MC0;
    TA0CCTL0 &= ~(CM0 + CM1); // disable CC interrupts
    TA0CCTL1 &= ~(CM0 + CM1);
    TA0CCTL2 &= ~(CM0 + CM1);
    TA0CTL &= ~TAIFG;
    TA0CTL |= TAIE; // enable timer overflow interrupt
}

inline void initBackchannel() {
    // setup backchannel at 9600 baud, 2 stop bits
    usciReset();
    BCCTL1 |= UCSSEL_3; // set uart to use SMCLK
    useBCUartPins();
    uartConfig();
    usciStart();
    enableUartTXInterrupt();
    clearUartTXInterruptFlag();
}

void handleJump(uint16_t *curr_addr) {
    uint16_t jump_addr, operator, src_bytes;
    opCode opcode;

    operator = readMem(*curr_addr);
    opcode = getOpCode(operator);
    jump_addr = 0;
    if (opcode.format == JUMP) {
        jump_addr = getJumpLocation(operator, *curr_addr);
    } else if (isCall(&opcode)) {
        src_bytes = readMem(*curr_addr + 2);
        jump_addr = getCallLocation(operator, src_bytes, *curr_addr);
    }
    if (jump_addr != 0 && jump_addr >= 0xC000 && jump_addr < 0xFFFF) {
        *curr_addr = jump_addr;
    }
}

void handleUp(uint16_t *curr_addr) {
    Instruction instr;
    uint16_t prev_addr;

    instr.address = 0xC000;
    while (instr.address < *curr_addr) {
        instr.operator = readMem(instr.address);
        instr.source = readMem(instr.address + 2);
        instr.destination = readMem(instr.address + 4);
        prev_addr = instr.address;
        nextAddress(&(instr.address), &instr);
    }
    *curr_addr = prev_addr;
}

void handleDown(uint16_t *curr_addr) {
    Instruction instr;

    instr.address = *curr_addr;
    instr.operator = readMem(instr.address);
    instr.source = readMem(instr.address + 2);
    instr.destination = readMem(instr.address + 4);
    nextAddress(curr_addr, &instr);
}

void displayAsm(uint16_t curr_addr) {
    Instruction instr;
    char buffer[31];
    uint16_t i;

    instr.address = curr_addr;
    for (i = 4; i > 0; i--) {
        instr.operator = readMem(instr.address);
        instr.source = readMem(instr.address + 2);
        instr.destination = readMem(instr.address + 4);
        waitPrintHex(instr.address);
        waitPrint(": ");
        getInstruction(buffer, &instr);
        waitPrint(buffer);
        if (i == 4) {
            waitPrint(" <");
        }
        waitPrint("\033[E"); // newline command
        nextAddress(&(instr.address), &instr);
    }
}

void displayBin(uint16_t curr_addr) {
    int encodingLength;
    Instruction instr;
    uint16_t i;

    instr.address = curr_addr;
    for (i = 4; i > 0; i--) {
        instr.operator = readMem(instr.address);
        instr.source = readMem(instr.address + 2);
        instr.destination = readMem(instr.address + 4);
        waitPrintHex(instr.address);
        waitPrint(": ");
        encodingLength = nextAddress(NULL, &instr);
        if (encodingLength == -1) {
            encodingLength = 1; // next address internally moves 1 word upon error
        }
        if (encodingLength >= 1) {
            waitPrintHex(instr.operator);
            waitPrint(" ");
            if (encodingLength >= 2) {
                waitPrintHex(instr.source);
                waitPrint(" ");
                if (encodingLength >= 3) {
                    waitPrintHex(instr.destination);
                    waitPrint(" ");
                }
            }
        }
        if (i == 4) {
            waitPrint("<");
        }
        waitPrint("\033[E"); // newline command
        nextAddress(&(instr.address), &instr);
    }
}

/**
 * main.c
 */
int main(void)
{
    uint16_t curr_addr;

    WDTCTL = WDTPW | WDTHOLD; // stop watchdog timer

    initButtons();
    setButtonCmd(SHOW_BTN); // indicates showing assembly
    initBackchannel();

    __bis_SR_register(GIE);
    waitPrint("\033[2J"); // clear screen command
    waitPrint("\033[H"); // home cursor command

    // take target under JTAG control
    initFSM();
    getDevice();
    haltCPU();

    curr_addr = 0xC000;
    while (true) {
        if (isButtonCmdSet(JUMP_BTN)) {
            handleJump(&curr_addr);
            clrButtonCmd(JUMP_BTN);
        }
        if (isButtonCmdSet(UP_BTN)) {
            handleUp(&curr_addr);
            clrButtonCmd(UP_BTN);
        }
        if (isButtonCmdSet(DOWN_BTN)) {
            handleDown(&curr_addr);
            clrButtonCmd(DOWN_BTN);
        }
        // display current instruction state
        waitPrint("\033[2J"); // clear screen command
        waitPrint("\033[H"); // home cursor command
        if (isButtonCmdSet(SHOW_BTN)) {
            displayAsm(curr_addr);
        } else {
            displayBin(curr_addr);
        }

        if (isButtonCmdSet(JUMP_BTN) || isButtonCmdSet(UP_BTN) || isButtonCmdSet(DOWN_BTN)) {
            continue; // missing an interrupt, update again
        }

        // go to sleep until woken from timer interrupt
        waitUart(); // finish sending uart data
        __bis_SR_register(GIE);
        __bis_SR_register(SCG0 | SCG1 | CPUOFF); // LPM3 until GPIO interrupt
    }
}

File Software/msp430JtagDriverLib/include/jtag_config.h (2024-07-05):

/*
 * jtag_config.h
 *
 *  Created on: Jun 19, 2023
 *      Author: Jaden Baptista
 */

#ifndef JTAG_CONFIG_H_
#define JTAG_CONFIG_H_

#include <msp430.h>
#include <stdint.h>

/*
 * JTAG GPIO Pins
 *
 * Naming is as seen in the interface reference and viewed from the target POV.
 */
#ifdef __MSP430F5529__
#define JTAGDIR     (P2DIR)     // port direction
#define JTAGIN      (P2IN)      // port input
#define JTAGOUT     (P2OUT)     // port output
#define JTAGREN     (P2REN)     // port resistor enable
#define RST         (0x01)      // Target MSP430 reset (0) (16)
#define TMS         (0x04)      // JTAG FSM control    (2) (7)
#define TCK         (0x08)      // JTAG clock input    (3) (6)
#define TDI         (0x10)      // JTAG data input and TCLK input (4) (14)
#define TDO         (0x20)      // JTAG data output (5) (15)
#define TEST        (0x40)      // JTAG enable pins (6) (17)
#endif

#ifdef __MSP430G2553__
#define JTAGDIR     (P1DIR)     // port direction
#define JTAGIN      (P1IN)      // port input
#define JTAGOUT     (P1OUT)     // port output
#define JTAGREN     (P1REN)     // port resistor enable
#define TEST        (BIT0)      // JTAG enable pins: target pin 17
#define RST         (BIT3)      // Target reset: target pin 16
#define TDO         (BIT4)      // JTAG data output: target pin 15
#define TDI         (BIT5)      // JTAG data input & TCLK input 14
#define TMS         (BIT6)      // JTAG FSM control: target pin 7
#define TCK         (BIT7)      // JTAG clock input: target pin 6
#endif



#endif /* JTAG_CONFIG_H_ */

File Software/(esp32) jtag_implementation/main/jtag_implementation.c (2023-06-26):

#include <stdio.h>
#include "freertos/FreeRTOS.h"
#include "freertos/task.h"
#include "driver/gpio.h"

#define HIGH 1
#define LOW 0
#define INPUT GPIO_MODE_INPUT
#define OUTPUT GPIO_MODE_OUTPUT

// JTAG pins are from the perspective of the MSP430
#define RST GPIO_NUM_14 // MSP430 reset                     (RX)  ->  (16) s2 (14/22)(GPIO/PHYSICAL)
#define TMS GPIO_NUM_45 // JTAG state machine control       (TX)  ->  (7)     (45/26)
#define TCK GPIO_NUM_34 // JTAG clock input                 (MO)  ->  (6)     (34/26)
#define TDI GPIO_NUM_33 // JTAG data input and TCLK input   (MI)  ->  (14)    (33/24)
#define TDO GPIO_NUM_21 // JTAG data output                 (21)  ->  (15)    (21/23)
#define TEN GPIO_NUM_13 // JTAG enable                      (SCL) ->  (17)    (13/21)

#define LOCATION 0x00

const uint8_t IR_ADDR_16BIT = 0x83;
const uint8_t IR_ADDR_CAPTURE = 0x84;
const uint8_t IR_DATA_TO_ADDR = 0x85;
const uint8_t IR_DATA_16BIT = 0x41;
const uint8_t IR_DATA_QUICK = 0x43;
const uint8_t IR_BYPASS = 0xFF;
const uint8_t IR_CNTRL_SIG_16BIT = 0x13;
const uint8_t IR_CNTRL_SIG_CAPTURE = 0x14;
const uint8_t IR_CNTRL_SIG_RELEASE = 0x15;
const uint8_t IR_DATA_PSA = 0x44;
const uint8_t IR_SHIFT_OUT_PSA = 0x46;
const uint8_t IR_Prepare_Blow = 0x22;
const uint8_t IR_Ex_Blow = 0x24;
const uint8_t IR_JMB_EXCHANGE = 0x61;

/*
    Shifts an 8-bit JTAG instruction into the JTAG
    instruction register via the TDI. At the same time,
    the 8-bit JTAG ID is shifted out via the TDO. Each
    instruction bit is captured from TDI on the rising
    edge of the TCK. Shifted LSB first.

    Returns: 8-bit JTAG ID
*/
uint8_t IR_SHIFT(uint8_t input_data) {
    uint16_t ret = 0x00;
    int prevTDI = gpio_get_level(TDI);

    // set TAP machine to Shift-IR state
    // TMS set through falling and rising edge
    gpio_set_level(TMS, HIGH);
    gpio_set_level(TCK, LOW);
    gpio_set_level(TCK, HIGH); // 1 (Select DR)

    gpio_set_level(TCK, LOW);
    gpio_set_level(TCK, HIGH); // 1 (Select IR)

    gpio_set_level(TMS, LOW);
    gpio_set_level(TCK, LOW);
    gpio_set_level(TCK, HIGH); // 0 (Capture IR)

    gpio_set_level(TCK, LOW);
    gpio_set_level(TCK, HIGH); // 0 (Shift IR)

    // shift data into IR
    uint8_t bit;
    for (int i = 0; i < 7; i++) {
        bit = input_data >> i;
        bit &= 0x01; // send the selected bit
        gpio_set_level(TDI, (uint32_t) bit);
        gpio_set_level(TCK, LOW);
        gpio_set_level(TCK, HIGH);
        uint16_t output = gpio_get_level(TDO);
        ret |= output << (7 - i);
    }

    // Send MSB and return to Run/Idle
    bit = input_data >> 7;
    bit &= 0x01;
    gpio_set_level(TMS, HIGH);
    gpio_set_level(TDI, bit);
    gpio_set_level(TCK, LOW);
    gpio_set_level(TCK, HIGH); // 1 (Exit IR)
    ret |= gpio_get_level(TDO);

    gpio_set_level(TDI, prevTDI);
    gpio_set_level(TCK, LOW);
    gpio_set_level(TCK, HIGH); // 1 (Update IR)

    gpio_set_level(TMS, LOW);
    gpio_set_level(TCK, LOW);
    gpio_set_level(TCK, HIGH); // 0 (IDLE)

    for (int i = 0; i < 4; i++) {
        gpio_set_level(TCK, LOW);
        gpio_set_level(TCK, HIGH);
    }

    return ret;
}

/*
    Shifts a 16-bit word into the JTAG data register (DR).
    The word is shifted, MSB first, via the TDI. At the
    same time, the last captured and stored value in the
    addressed data register is shifted out via the TDO. A
    new bit is present at TDO with a falling edge of TCK.
    Shifted MSB first.

    Returns: Last captured and stored value in the
    addressed data register.
*/
uint16_t DR_SHIFT(uint16_t input_data) {
    uint16_t ret = 0x0000;
    int prevTDI = gpio_get_level(TDI);

    // set TAP machine to Shift-DR state
    // TMS set through falling and rising edge
    gpio_set_level(TMS, HIGH);
    gpio_set_level(TCK, LOW);
    gpio_set_level(TCK, HIGH); // 1 (Select DR)

    gpio_set_level(TMS, LOW);
    gpio_set_level(TCK, LOW);
    gpio_set_level(TCK, HIGH); // 0 (Capture DR)

    gpio_set_level(TCK, LOW);
    gpio_set_level(TCK, HIGH); // 0 (Shift DR)

    // shift data into DR
    uint16_t bit;
    for (int i = 15; i > 0; i--) {
        bit = input_data >> i;
        bit &= 0x0001; // send the selected bit
        gpio_set_level(TDI, (uint32_t) bit);
        gpio_set_level(TCK, LOW);
        gpio_set_level(TCK, HIGH);
        uint16_t output = gpio_get_level(TDO);
        ret |= output << i;
    }
    // Send LSB and return to Run/Idle
    bit = input_data;
    bit &= 0x0001;
    gpio_set_level(TMS, HIGH);
    gpio_set_level(TDI, bit);
    gpio_set_level(TCK, LOW);
    gpio_set_level(TCK, HIGH); // 1 (Exit DR)
    ret |= gpio_get_level(TDO);

    gpio_set_level(TDI, prevTDI);
    gpio_set_level(TCK, LOW);
    gpio_set_level(TCK, HIGH); // 1 (Update DR)

    gpio_set_level(TMS, LOW);
    gpio_set_level(TCK, LOW);
    gpio_set_level(TCK, HIGH); // 0 (IDLE)

    for (int i = 0; i < 4; i++) {
        gpio_set_level(TCK, LOW);
        gpio_set_level(TCK, HIGH);
    }

    return ret;
}

/*
    Sets TCLK to LOW, which acts as the falling edge of
    the CPU clock. Executed in the Run/Idle state. Note
    that the MSP430 is not pipelined, so a full TCLK cycle
    executes the CPU instruction located at the PC.
*/
void ClrTCLK() {
    gpio_set_level(TDI, LOW);
}

/*
    Sets TCLK to HIGH, which acts as the rising edge of
    the CPU clock. Executed in the Run/Idle state. Note
    that the MSP430 is not pipelined, so a full TCLK cycle
    executes the CPU instruction located at the PC.
*/
void SetTCLK() {
    gpio_set_level(TDI, HIGH);
}

/*
    Takes the CPU under JTAG Control.
*/
void GetDevice() {
    IR_SHIFT(IR_CNTRL_SIG_16BIT);
    DR_SHIFT((uint16_t) 0x2401);
    IR_SHIFT(IR_CNTRL_SIG_CAPTURE);
    printf("Syncing CPU...\n");
    while (true) {
        uint16_t TDOword = DR_SHIFT((uint16_t) 0x0000);
        if ((TDOword & 0x0200) != 0) {
            printf("Sync Successful!\n");
            return;
        }
    }   
}

/*
    Releases CPU from JTAG control. The target CPU
    starts program execution with the address stored
    at location 0x0FFFE (reset vector).
    
    This function is very distinct from ReleaseCPU!
*/
void ReleaseDevice() {
    IR_SHIFT(IR_CNTRL_SIG_16BIT);
    DR_SHIFT((uint16_t) 0x2C01); // apply reset
    DR_SHIFT((uint16_t) 0x2401); // remove reset
    IR_SHIFT(IR_CNTRL_SIG_RELEASE);
}

/*
    Sets the CPU to instruction-fetch state. This is used
    to execute an instruction presented by a host over the
    JTAG port.
*/
void SetInstrFetch() {
    IR_SHIFT(IR_CNTRL_SIG_CAPTURE);
    uint16_t data = DR_SHIFT((uint16_t) 0x0000);
    for (int i = 0; i < 8; i++) {
        printf("InstrFetch: 0x%X\n", data);
        if ((data & 0x0080) != 0) return;
        ClrTCLK();
        SetTCLK();
    }
    printf("SetInstrFetch Unsuccessful!\n");
}
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

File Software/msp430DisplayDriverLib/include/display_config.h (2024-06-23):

/*
 * display_config.h
 *
 *  Created on: Jun 20, 2024
 *      Author: bapti
 */

#ifndef INCLUDE_DISPLAY_CONFIG_H_
#define INCLUDE_DISPLAY_CONFIG_H_

#ifdef __MSP430G2553__
#define DISPLAYDATADIR      (P1DIR)     // data port direction
#define DISPLAYDATASEL      (P1SEL)     // display port select 1
#define DISPLAYDATASEL2     (P1SEL2)    // display port select 2
#define DISPLAYDATAIN       (P1IN)      // data port input
#define DISPLAYDATAOUT      (P1OUT)     // data port output
#define DISPLAYDATAREN      (P1REN)     // data port register enable
#define DB4                 (BIT4)      // data bit 4 pin
#define DB5                 (BIT5)      // data bit 5 pin
#define DB6                 (BIT6)      // data bit 6 pin
#define DB7                 (BIT7)      // data bit 7 pin
#define DISPLAYCNTLDIR      (P2DIR)     // control port direction
#define DISPLAYCNTLIN       (P2IN)      // control port input
#define DISPLAYCNTLOUT      (P2OUT)     // control port output
#define DISPLAYCNTLREN      (P2REN)     // control port register enable
#define DISPLAYCNTLSEL      (P2SEL)     // control port select 1
#define DISPLAYCNTLSEL2     (P2SEL2)    // control port select 2
#define RW                  (BIT0)      // select read or write. 0: write, 1: read
#define EN1                 (BIT1)      // top lines operation enable, falling edge triggered
#define EN2                 (BIT2)      // bottom lines operation enable, falling edge triggered
#define RS                  (BIT3)      // register select. 0: command, 1: data
#endif

#endif /* INCLUDE_DISPLAY_CONFIG_H_ */

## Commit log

2023-03-20 create kicad project
    [msp-debugger.kicad_pcb, msp-debugger.kicad_sch]
2023-04-04 working on things
    [msp-debugger.kicad_sch]
2023-04-05 switch voltage divider for regulator
    [msp-debugger-con.kicad_sch]
2023-04-06 use digikey/espressif libraries
    [msp-debugger.kicad_sch]
2023-04-06 finalize schematic
    [msp-debugger.kicad_sch]
2023-04-06 update components & footprints
    [msp-debugger.kicad_sch]
2023-04-06 complete rough footprints
    [msp-debugger.kicad_sch]
2023-04-06 route rough traces
    [msp-debugger.kicad_pcb, msp-debugger.kicad_sch]
2023-04-12 rough draft layout
    [msp-debugger.kicad_pcb, msp-debugger.kicad_sch]
2023-04-12 add test points
    [msp-debugger.kicad_pcb, msp-debugger.kicad_sch]
2023-04-12 just in case
2023-04-17 finalized pcb
    [msp-debugger.kicad_pcb, msp-debugger.kicad_sch]
2023-04-17 increase mounting drill size by 0.1mm
    [msp-debugger.kicad_pcb]
2023-04-17 add digikey and espressif libs
    [familylist_refdes.csv]
2023-04-18 gerber files
    [msp-debugger-B_Cu.gbl, msp-debugger-B_Cu.gbr, msp-debugger-B_Mask.gbr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]
2023-04-18 zip files
    [msp-debugger.kicad_pcb]
2023-04-18 fix pour to edge clearance
    [msp-debugger-B_Cu.gbl, msp-debugger-B_Cu.gbr, msp-debugger-B_Mask.gbr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]
2023-04-18 complete hardware!
    [Final BOM.xlsx, Project BOM.xlsx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]
2023-07-22 reorganize repository
    [Final BOM.xlsx, Project BOM.xlsx, familylist_refdes.csv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]
2023-09-17 get msp430 jtag implementation to working state
    [main.obj]
2023-10-20 make various changes, fix .gitignores
    [main.c]
2024-05-27 Implement backchannel UART driver
2024-05-28 create testing framework
2024-05-29 refactor libraries & remove backchannel tests to fix build errors
    [bc_uart.c, jtag_config.h, main.c]
2024-06-01 fix testing framework
2024-06-03 add blinky and try to fix bug
    [main.obj]
2024-06-04 fix setTCLK and clrTCLK bug
    [main.obj]
2024-06-06 add msp430g2553 controller support & purge build dirs
    [main.obj]
2024-06-06 begin updating pcb with g2553
    [Project BOM.xlsx, msp-debugger.kicad_pcb, msp-debugger.kicad_sch]
2024-06-06 route new pcb
    [bc_uart.obj, control_tests.obj, fsm_tests.obj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]
2024-06-08 finish disassembler
    [bc_uart.obj, control_tests.obj, fsm_tests.obj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]
2024-06-09 fix jump bug and autoincrement constant bug
    [disassembler.c, main.c]
2024-06-10 update schematic to use length 40 lcd
    [Project BOM.xlsx, msp-debugger.kicad_sch]
2024-06-11 update schematic to active high reset
    [Project BOM.xlsx, msp-debugger.kicad_sch]
2024-06-11 reroute pcb for 40 line lcd screen
    [Project BOM.xlsx, msp-debugger.kicad_pcb, msp-debugger.kicad_sch]
2024-06-23 begin work on display driver
    [main.obj]
2024-06-23 remove gerber files
    [msp-debugger-B_Cu.gbl, msp-debugger-B_Mask.gbs, msp-debugger-B_Paste.gbp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]
2024-06-27 fix hardware issues and route small pcb
    [Project BOM.xlsx, msp-debugger.kicad_pcb, msp-debugger.kicad_sch]
2024-06-28 gerber pcb and update BOM
    [Project BOM.xlsx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]
2024-07-05 implement rudimentary button irq
2024-07-06 add button debouncing
2024-07-11 fix bug when only dest consumes word in double operand
    [disassembler.c, main.c]
2024-07-18 reduce power consumption using low power modes
2024-08-02 clean up button code
2024-08-02 clean up functions & recalibrate debounce value
    [integration_tests.obj, main.obj]
